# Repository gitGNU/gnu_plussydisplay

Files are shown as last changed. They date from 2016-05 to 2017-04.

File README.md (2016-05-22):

# Plussy Display Introduction

This repository contains free software and hardware design components for a small LED matrix resembling FSFE's plussy mascot. It is intended to be used, e.g., as an eyecatcher for fellowship events.

## License Information

All files in this project (except some configuration files where stated in their header) are licensed under the GPLv3 license as stated in the next section (GPLv3 License Statement).

## GPLv3 License Statement

Plussy Display
Copyright (C) 2015  Christian Carlowitz <chca@cmesh.de>

This program is free software: you can redistribute it and/or modify
it under the terms of the GNU General Public License as published by
the Free Software Foundation, either version 3 of the License, or
(at your option) any later version.

This program is distributed in the hope that it will be useful,
but WITHOUT ANY WARRANTY; without even the implied warranty of
MERCHANTABILITY or FITNESS FOR A PARTICULAR PURPOSE.  See the
GNU General Public License for more details.

You should have received a copy of the GNU General Public License
along with this program.  If not, see <http://www.gnu.org/licenses/>.

# Usage
## Adding new animations

* install dependencies for simulator (gcc, make, python2.7 including development headers, python-pygame)
* add new animation file in _uc/src/animations_, e.g., by copying an existing file
* rename animation function to match file name
* register animation function in _common.h_ for microcontroller (add declaration and _animTable_ entry)
* run `make ANIM=anim_funcname` in folder _sim_ to test

## Compiling microcontroller code

* install dependencies (gcc-arm-embedded from https://launchpad.net/gcc-arm-embedded, openocd, make)
* get libopencm3 (run `git submodule init`, enter _uc/libopencm3_, run `make`)
* run `make` or `make V=1` (verbose) in folder _uc_

## Flashing microcontroller

* find out openocd name for your JTAG adapter
* change parameter _OOCD_INTERFACE_ in file _uc/libopencm3.target.mk_ accordingly
* run `make flash` or `make flash V=1` (verbose) in folder _uc_

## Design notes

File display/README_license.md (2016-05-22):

# License Information

This directory contains laser cutter templates as `*.svg` files as well as PCB schematics, libraries and layouts created with KiCAD. All of these files, which partly do not support incorporating license information, are license under the GPLv3 license as stated in the following section.

## GPLv3 License Statement

Plussy Display
Copyright (C) 2015  Christian Carlowitz <chca@cmesh.de>

This program is free software: you can redistribute it and/or modify
it under the terms of the GNU General Public License as published by
the Free Software Foundation, either version 3 of the License, or
(at your option) any later version.

This program is distributed in the hope that it will be useful,
but WITHOUT ANY WARRANTY; without even the implied warranty of
MERCHANTABILITY or FITNESS FOR A PARTICULAR PURPOSE.  See the
GNU General Public License for more details.

You should have received a copy of the GNU General Public License
along with this program.  If not, see <http://www.gnu.org/licenses/>.

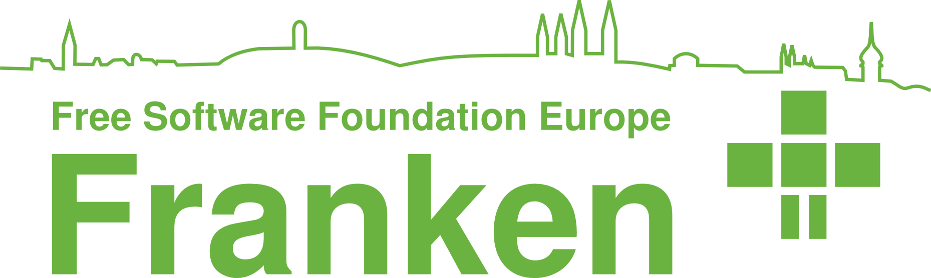
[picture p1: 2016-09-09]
server/fellowship_franken.png

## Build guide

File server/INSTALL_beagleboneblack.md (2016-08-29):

# License

Copying and distribution of this file, with or without modification,
are permitted in any medium without royalty provided the copyright
notice and this notice are preserved.  This file is offered as-is,
without any warranty.

# Installation on BeagleBoneBlack

Note: This script has been updated for Debian jessie based images; particularly these: http://elinux.org/Beagleboard:BeagleBoneBlack_Debian#Debian_Image_Testing_Snapshots

Log of all steps performed:
* remove `contrib` and `non-free` flags in `/etc/apt/sources.list` (use free software only)
* `apt-get update` and `apt-get upgrade`
* disable graphical interface: `update-rc.d -f lightdm remove`
* disable network service: `update-rc.d -f wicd remove`
* disable xrdp service: `update-rc.d -f xrdp remove`
* disable avahi: `update-rc.d -f avahi-daemon remove`
* `apt-get purge avahi-daemon`
* some error with led_aging startup script, added missing LSB info
* install `lsof`
* disable beagle bone services (occupying, e.g., port 80):
	* `systemctl disable bonescript.service`
	* `systemctl disable bonescript.socket`
	* `systemctl disable bonescript-autorun.service`
	* `systemctl disable cloud9.service`
	* `systemctl disable cloud9.socket`
* since some services are somehow enabled again by systemd:
	* `cd /lib/systemd/system`
	* `mv cloud9.service cloud9.service.disabled`
	* `mv cloud9.socket cloud9.socket.disabled`
* fimware for WLAN
	* recommended stick "TL-WN722N" (Atheros AR9271) requires firmware
	* free firmware not available in debian main
	* e.g., extract from Trisquel package "open-atk9k-htc-firmware": `/lib/firmware/htc_9271.fw`
* hostapd
	* install: `apt-get install hostapd  iw iwconfig wpa-supplicant`
	* add config `/etc/hostapd/hostapd.conf`
	* register config in `/etc/default/hostapd`
	* setup wlan0 in `/etc/network/interfaces`
* udhcpd
	* add config `/etc/udhcpd.conf.wlan0`
	* add post-up call to udhcpd
* set root password, set debian user password
* install python3: `apt-get install python3 python3-serial`
* install plussy server script:
	* copy to /usr/local/sbin
	* create user: `adduser --system --home /tmp --shell /bin/bash --no-create-home --disabled-login --ingroup dialout plussy`
	* register with systemd (copy script to `/etc/systemd/system/`)
* read-only rootfs:
	* add "ro" to to /boot/uboot/uEnv.txt (mmcargs)
	* add "ro" to "/" and "/boot/uboot" in /etc/fstab
	* add some temp filesystems (see fstab)
	* enhance bashrc (see bash.bashrc)
* apache
	* /etc/apache2/envvars: move log dir to /var/log (no subdir)
	* mv default site on 8080 to available (which disables it)
	* add new default site ("default" file, see below)
	* enable new default site with symlink
	* enable cgi with `a2enmod cgi`
* bind
	* `apt-get install bind9`
	* copy zone files, register fsfe zone (see files below)
* using UART different than UART1
	* install capemgr stuff according to `https://github.com/beagleboard/bb.org-overlays`
	* disable HDMI in /boot/uEnv.txt (uncomment `dtb=am335x-boneblack-emmc-overlay.dtb`)
	* enable UART5 with `cape_enable=bone_capemgr.enable_partno=BB-UART5`
	* change port to ttyO5 in `/etc/systemd/system/plussy-server.service`

Files:
* `/etc/hostapd/hostapd.conf`
* `/etc/udhcpd.conf.wlan0`
* `/etc/network/interfaces`
* `/etc/bash.bashrc`
* `/etc/fstab`
* `/etc/apache2/sites-available/default`
* `/etc/bind/{db.4.168.192,db.fsfe,named.conf.local}`
* `/etc/systemd/system/plussy-server.service`
* `/usr/local/sbin/server.py`
* `/var/www/server_web.py`

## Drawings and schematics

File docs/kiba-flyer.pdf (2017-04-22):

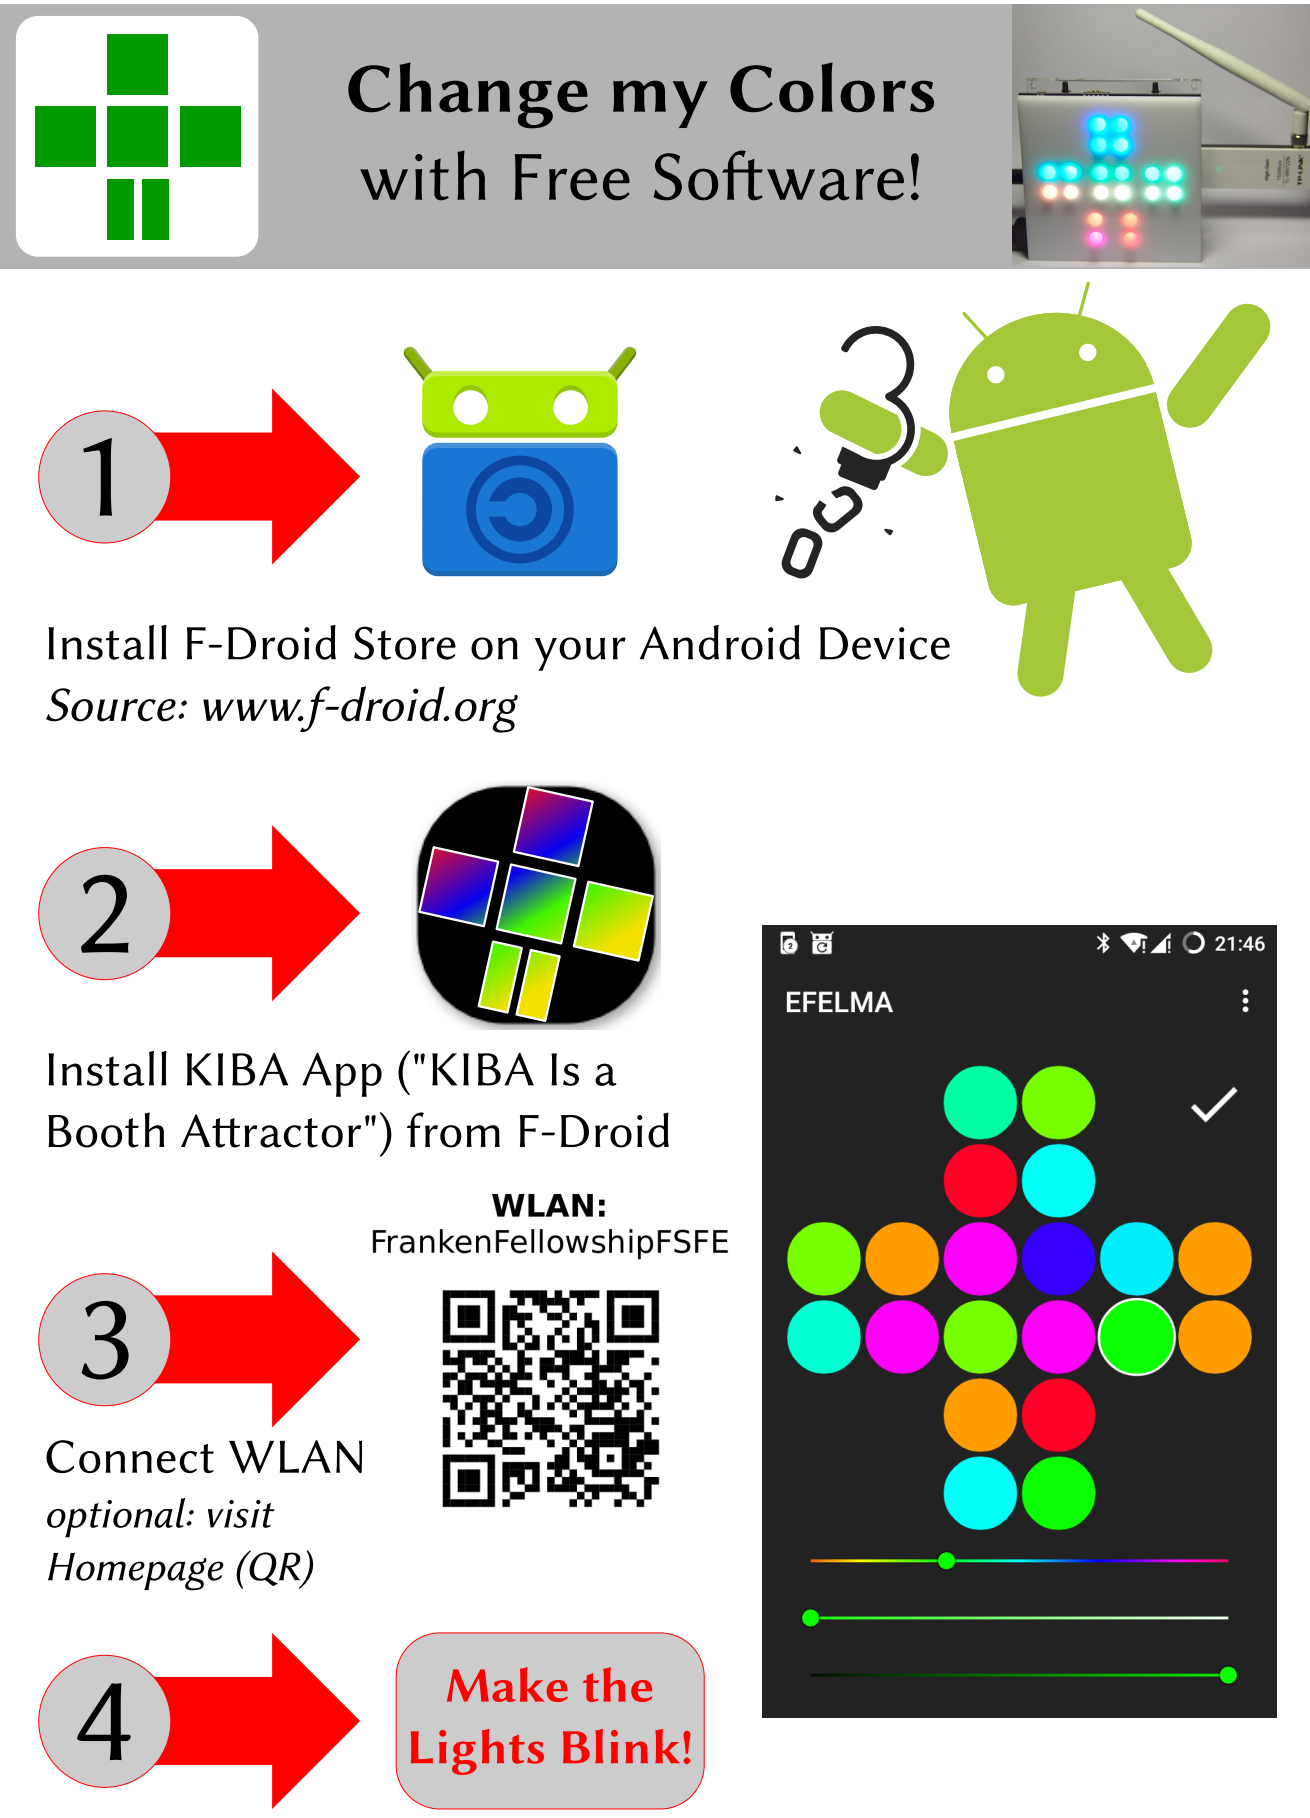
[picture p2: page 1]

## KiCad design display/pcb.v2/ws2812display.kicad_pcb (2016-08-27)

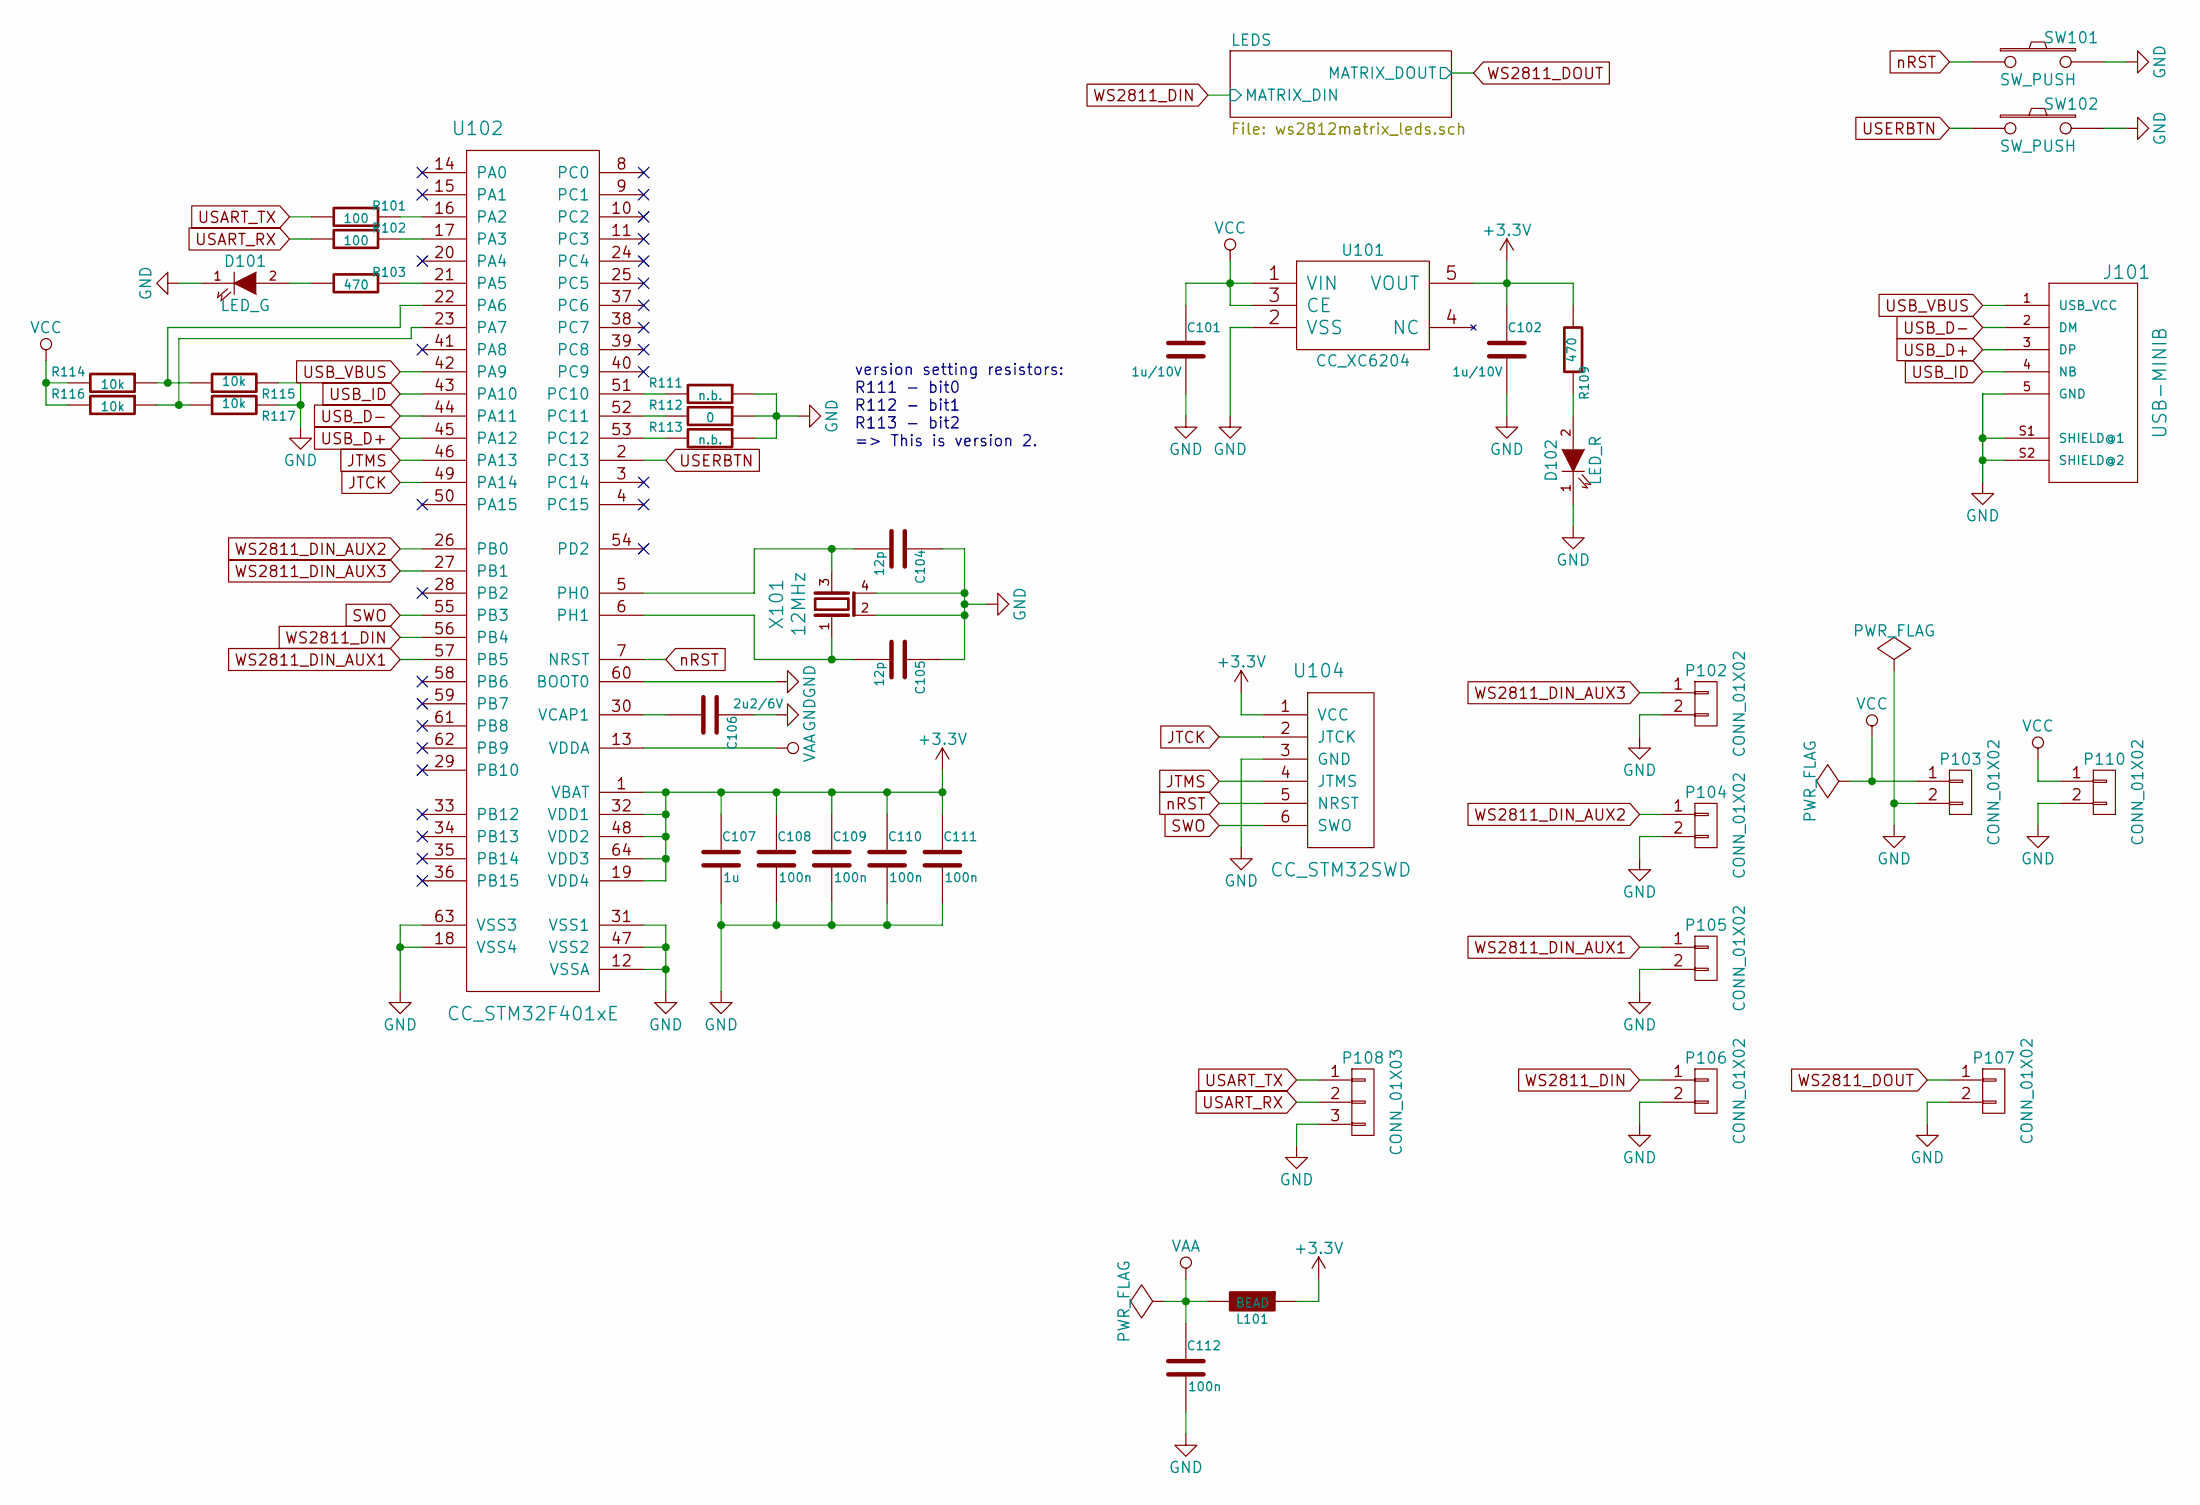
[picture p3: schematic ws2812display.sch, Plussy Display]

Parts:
C101, C102: 1u/10V; rcl-cc-0603
C104, C105: 12p; rcl-cc-0603
C106: 2u2/6V; rcl-cc-0603
C107: 1u; rcl-cc-0603
C108, C109, C110, C111, C112: 100n; rcl-cc-0603
D101: LED_G; LED-0603
D102: LED_R; LED-0603
J101: USB-MINIB; con-usb-USB-B-MINI-THD
L101: BEAD; rcl-cc-0603
P102, P104, P105, P106, P107: CONN_01X02; Pin_Header_Straight_1x02
P103, P110: CONN_01X02; con-ria-TYPE_230_249_2PIN
P108: CONN_01X03; Pin_Header_Straight_1x03
R101, R102: 100; rcl-cc-0603
R103, R109: 470; rcl-cc-0603
R111, R113: n.b.; rcl-cc-0603
R112: 0; rcl-cc-0603
R114, R115, R116, R117: 10k; rcl-cc-0603
SW101, SW102: SW_PUSH; TASTER_3305B
U101: CC_XC6204; SOT23-5
U102: CC_STM32F401xE; lqfp64
U104: CC_STM32SWD; Pin_Header_Straight_1x06
X101: 12MHz; Q_EUROQUARTZ_MJ_3x5x1

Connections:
+3V3: C102.1, C107.1, C108.1, C109.1, C110.1, C111.1, L101.1, R109.2, U101.5 (VOUT), U102.1 (VBAT), U102.19 (VDD4), U102.32 (VDD1), U102.48 (VDD2), U102.64 (VDD3), U104.1 (VCC)
GND: C101.2, C102.2, C104.1, C105.1, C106.1, C107.2, C108.2, C109.2, C110.2, C111.2, C112.2, D101.1 (K), D102.1 (K), J101.5 (GND), J101.S1 (SHIELD@1), J101.S2 (SHIELD@2), P102.2, P103.2, P104.2, P105.2, P106.2, P107.2, P108.3, P110.2, R111.1, R112.1, R113.1, R115.2, R117.2, SW101.2, SW102.2, U101.2 (VSS), U102.12 (VSSA), U102.18 (VSS4), U102.31 (VSS1), U102.47 (VSS2), U102.60 (BOOT0), U102.63 (VSS3), U104.3 (GND), X101.2 (GND), X101.4 (GND); also elsewhere on the board
JTCK: U102.49 (PA14), U104.2 (JTCK)
JTMS: U102.46 (PA13), U104.4 (JTMS)
unnamed: C104.2, U102.5 (PH0), X101.3
unnamed: C105.2, U102.6 (PH1), X101.1
unnamed: C106.2, U102.30 (VCAP1)
unnamed: D101.2 (A), R103.2
unnamed: D102.2 (A), R109.1
unnamed: R101.1, U102.16 (PA2)
unnamed: R102.1, U102.17 (PA3)
unnamed: R103.1, U102.21 (PA5)
unnamed: R111.2, U102.51 (PC10)
unnamed: R112.2, U102.52 (PC11)
unnamed: R113.2, U102.53 (PC12)
unnamed: R114.1, R115.1, U102.22 (PA6)
unnamed: R116.1, R117.1, U102.23 (PA7)
SWO: U102.55 (PB3), U104.6 (SWO)
USART_RX: P108.2, R102.2
USART_TX: P108.1, R101.2
USB_D+: J101.3 (DP), U102.45 (PA12)
USB_D-: J101.2 (DM), U102.44 (PA11)
USB_ID: J101.4 (NB), U102.43 (PA10)
USB_VBUS: J101.1 (USB_VCC), U102.42 (PA9)
USERBTN: SW102.1, U102.2 (PC13)
VAA: C112.1, L101.2, U102.13 (VDDA)
VCC: C101.1, P103.1, P110.1, R114.2, R116.2, U101.1 (VIN), U101.3 (CE); also elsewhere on the board
WS2811_DIN: P106.1, U102.56 (PB4); also elsewhere on the board
WS2811_DIN_AUX1: P105.1, U102.57 (PB5)
WS2811_DIN_AUX2: P104.1, U102.26 (PB0)
WS2811_DIN_AUX3: P102.1, U102.27 (PB1)
WS2811_DOUT: P107.1; also elsewhere on the board
nRST: SW101.1, U102.7 (NRST), U104.5 (NRST)

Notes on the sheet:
version setting resistors: R111 - bit0 R112 - bit1 R113 - bit2 => This is version 2.

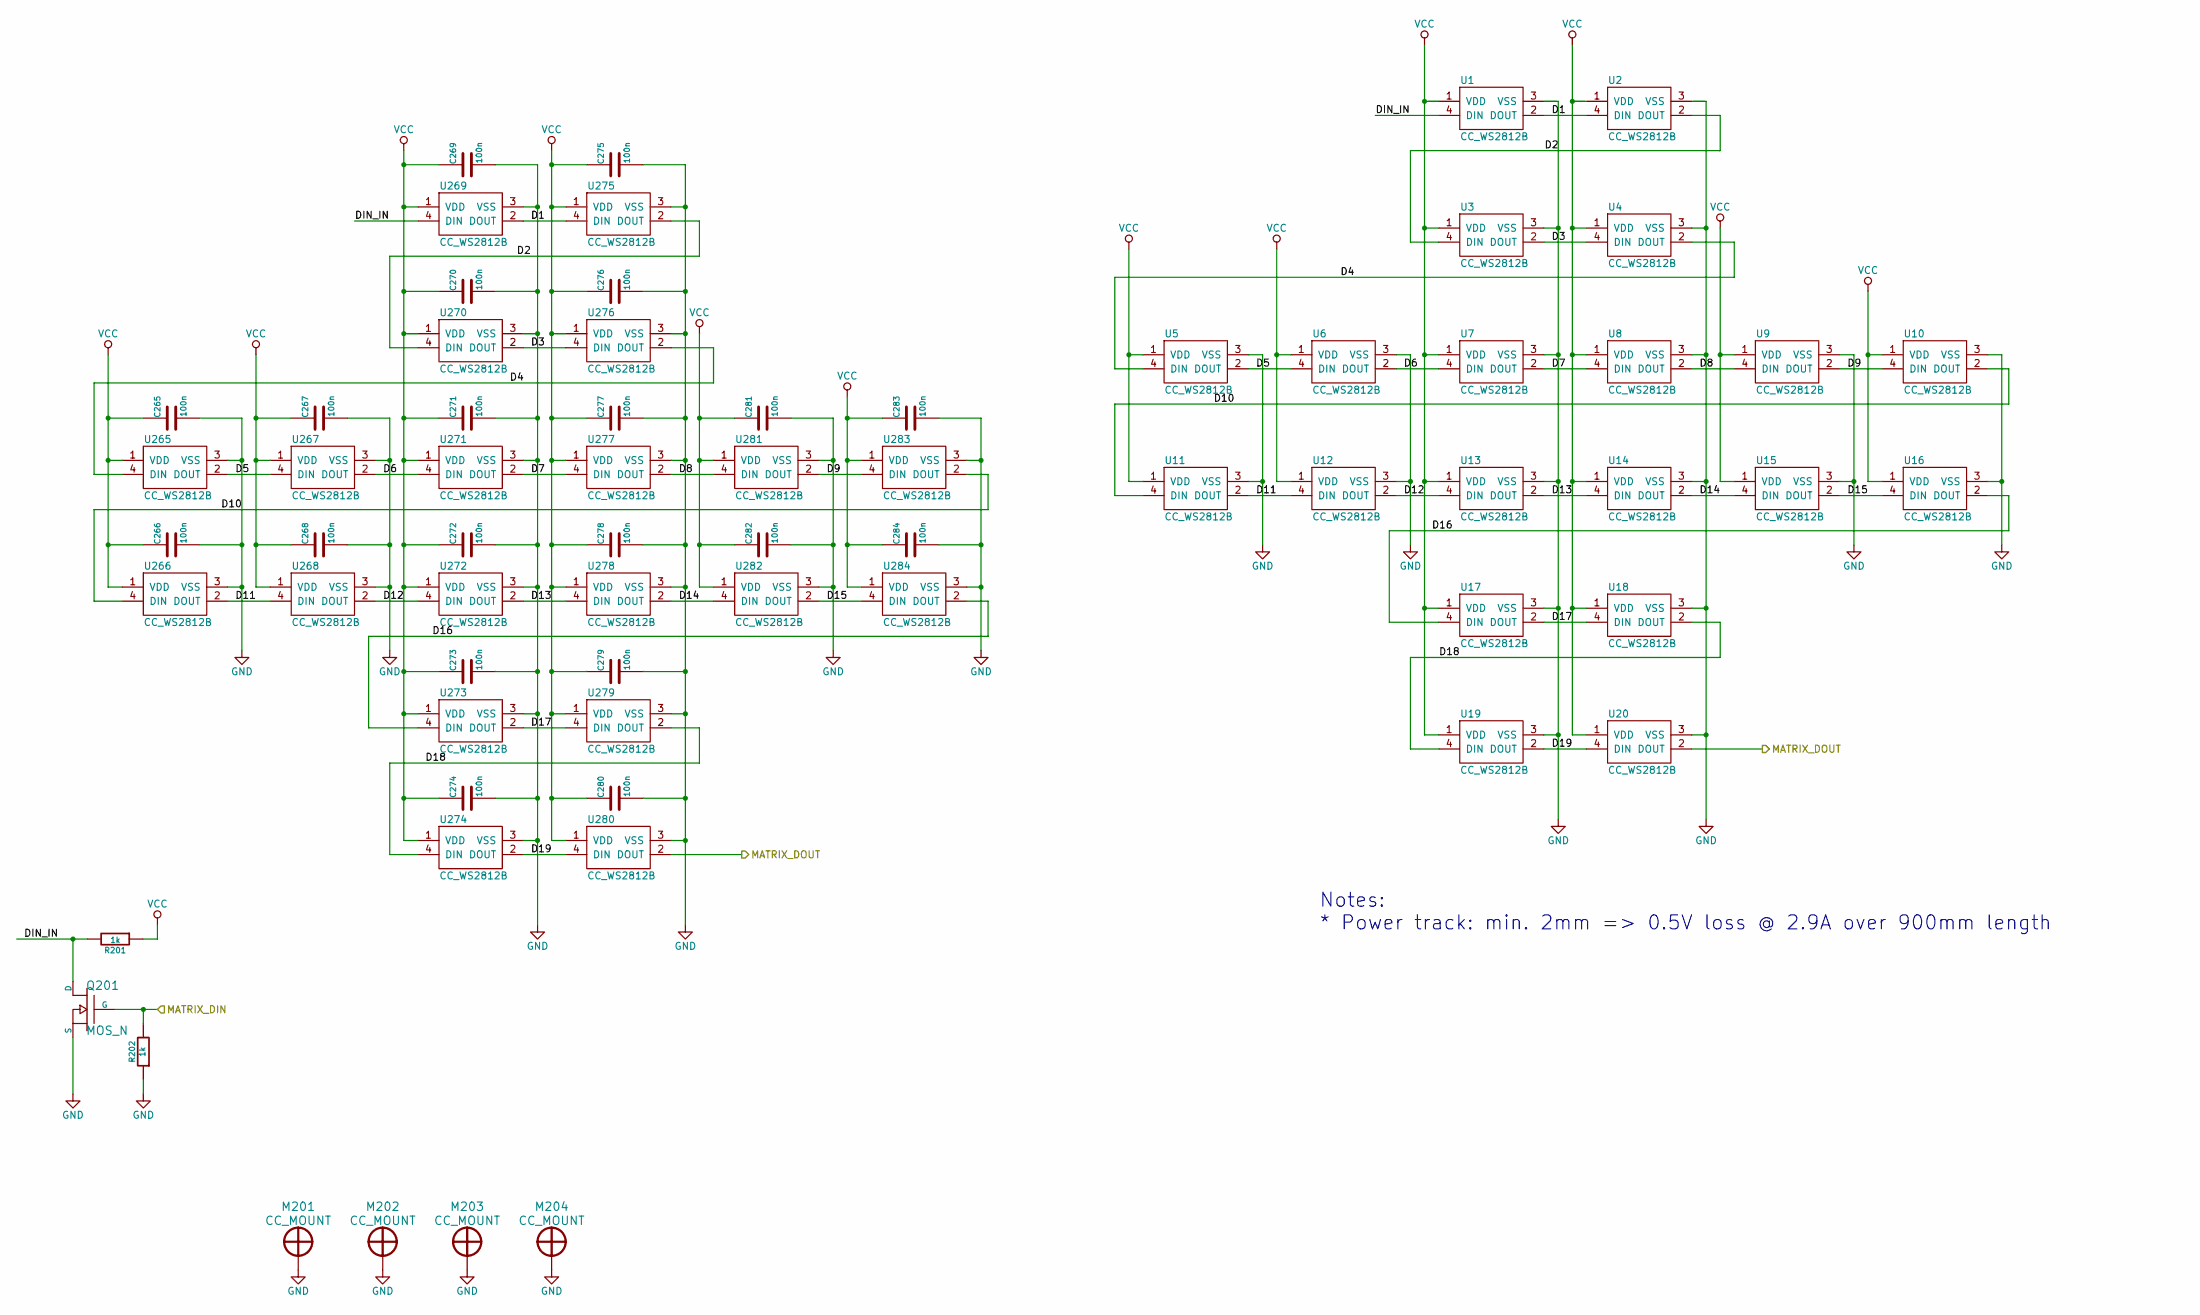
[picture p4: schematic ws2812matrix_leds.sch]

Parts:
C265, C266, C267, C268, C269, C270, C271, C272, C273, C274, C275, C276, C277, C278, C279, C280, C281, C282, C283, C284: 100n; rcl-cc-0603
M201, M202, M203, M204: CC_MOUNT; CC_MOUNT_PLATED_M3
Q201: MOS_N; CC_SOT23_MOS1
R201, R202: 1k; rcl-cc-0603
U1, U2, U3, U4, U5, U6, U7, U8, U9, U10, U11, U12, U13, U14, U15, U16, U17, U18, U19, U20: CC_WS2812B; WS2812B
U265, U266, U267, U268, U269, U270, U271, U272, U273, U274, U275, U276, U277, U278, U279, U280, U281, U282, U283, U284: CC_WS2812B; WS2812B_DUAL

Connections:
/LEDS/D1: U1.2 (DOUT), U2.4 (DIN), U269.2 (DOUT), U275.4 (DIN)
/LEDS/D2: U2.2 (DOUT), U3.4 (DIN), U270.4 (DIN), U275.2 (DOUT)
/LEDS/D3: U3.2 (DOUT), U4.4 (DIN), U270.2 (DOUT), U276.4 (DIN)
/LEDS/D4: U4.2 (DOUT), U5.4 (DIN), U265.4 (DIN), U276.2 (DOUT)
/LEDS/D5: U5.2 (DOUT), U6.4 (DIN), U265.2 (DOUT), U267.4 (DIN)
/LEDS/D6: U6.2 (DOUT), U7.4 (DIN), U267.2 (DOUT), U271.4 (DIN)
/LEDS/D7: U7.2 (DOUT), U8.4 (DIN), U271.2 (DOUT), U277.4 (DIN)
/LEDS/D8: U8.2 (DOUT), U9.4 (DIN), U277.2 (DOUT), U281.4 (DIN)
/LEDS/D9: U9.2 (DOUT), U10.4 (DIN), U281.2 (DOUT), U283.4 (DIN)
/LEDS/D10: U10.2 (DOUT), U11.4 (DIN), U266.4 (DIN), U283.2 (DOUT)
/LEDS/D11: U11.2 (DOUT), U12.4 (DIN), U266.2 (DOUT), U268.4 (DIN)
/LEDS/D12: U12.2 (DOUT), U13.4 (DIN), U268.2 (DOUT), U272.4 (DIN)
/LEDS/D13: U13.2 (DOUT), U14.4 (DIN), U272.2 (DOUT), U278.4 (DIN)
/LEDS/D14: U14.2 (DOUT), U15.4 (DIN), U278.2 (DOUT), U282.4 (DIN)
/LEDS/D15: U15.2 (DOUT), U16.4 (DIN), U282.2 (DOUT), U284.4 (DIN)
/LEDS/D16: U16.2 (DOUT), U17.4 (DIN), U273.4 (DIN), U284.2 (DOUT)
/LEDS/D17: U17.2 (DOUT), U18.4 (DIN), U273.2 (DOUT), U279.4 (DIN)
/LEDS/D18: U18.2 (DOUT), U19.4 (DIN), U274.4 (DIN), U279.2 (DOUT)
/LEDS/D19: U19.2 (DOUT), U20.4 (DIN), U274.2 (DOUT), U280.4 (DIN)
/LEDS/DIN_IN: Q201.D, R201.2, U1.4 (DIN), U269.4 (DIN)
GND: C265.2, C266.2, C267.2, C268.2, C269.2, C270.2, C271.2, C272.2, C273.2, C274.2, C275.2, C276.2, C277.2, C278.2, C279.2, C280.2, C281.2, C282.2, C283.2, C284.2, M201.1, M202.1, M203.1, M204.1, Q201.S, R202.1, U1.3 (VSS), U2.3 (VSS), U3.3 (VSS), U4.3 (VSS), U5.3 (VSS), U6.3 (VSS), U7.3 (VSS), U8.3 (VSS), U9.3 (VSS), U10.3 (VSS), U11.3 (VSS), U12.3 (VSS), U13.3 (VSS), U14.3 (VSS), U15.3 (VSS), U16.3 (VSS), U17.3 (VSS), U18.3 (VSS), U19.3 (VSS), U20.3 (VSS), U265.3 (VSS), U266.3 (VSS), U267.3 (VSS), U268.3 (VSS), U269.3 (VSS), U270.3 (VSS), U271.3 (VSS), U272.3 (VSS), U273.3 (VSS), U274.3 (VSS), U275.3 (VSS), U276.3 (VSS), U277.3 (VSS), U278.3 (VSS), U279.3 (VSS), U280.3 (VSS), U281.3 (VSS), U282.3 (VSS), U283.3 (VSS), U284.3 (VSS); also elsewhere on the board
VCC: C265.1, C266.1, C267.1, C268.1, C269.1, C270.1, C271.1, C272.1, C273.1, C274.1, C275.1, C276.1, C277.1, C278.1, C279.1, C280.1, C281.1, C282.1, C283.1, C284.1, R201.1, U1.1 (VDD), U2.1 (VDD), U3.1 (VDD), U4.1 (VDD), U5.1 (VDD), U6.1 (VDD), U7.1 (VDD), U8.1 (VDD), U9.1 (VDD), U10.1 (VDD), U11.1 (VDD), U12.1 (VDD), U13.1 (VDD), U14.1 (VDD), U15.1 (VDD), U16.1 (VDD), U17.1 (VDD), U18.1 (VDD), U19.1 (VDD), U20.1 (VDD), U265.1 (VDD), U266.1 (VDD), U267.1 (VDD), U268.1 (VDD), U269.1 (VDD), U270.1 (VDD), U271.1 (VDD), U272.1 (VDD), U273.1 (VDD), U274.1 (VDD), U275.1 (VDD), U276.1 (VDD), U277.1 (VDD), U278.1 (VDD), U279.1 (VDD), U280.1 (VDD), U281.1 (VDD), U282.1 (VDD), U283.1 (VDD), U284.1 (VDD); also elsewhere on the board
WS2811_DIN: Q201.G, R202.2; also elsewhere on the board
WS2811_DOUT: U20.2 (DOUT), U280.2 (DOUT); also elsewhere on the board

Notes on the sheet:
Notes: * Power track: min. 2mm => 0.5V loss @ 2.9A over 900mm length

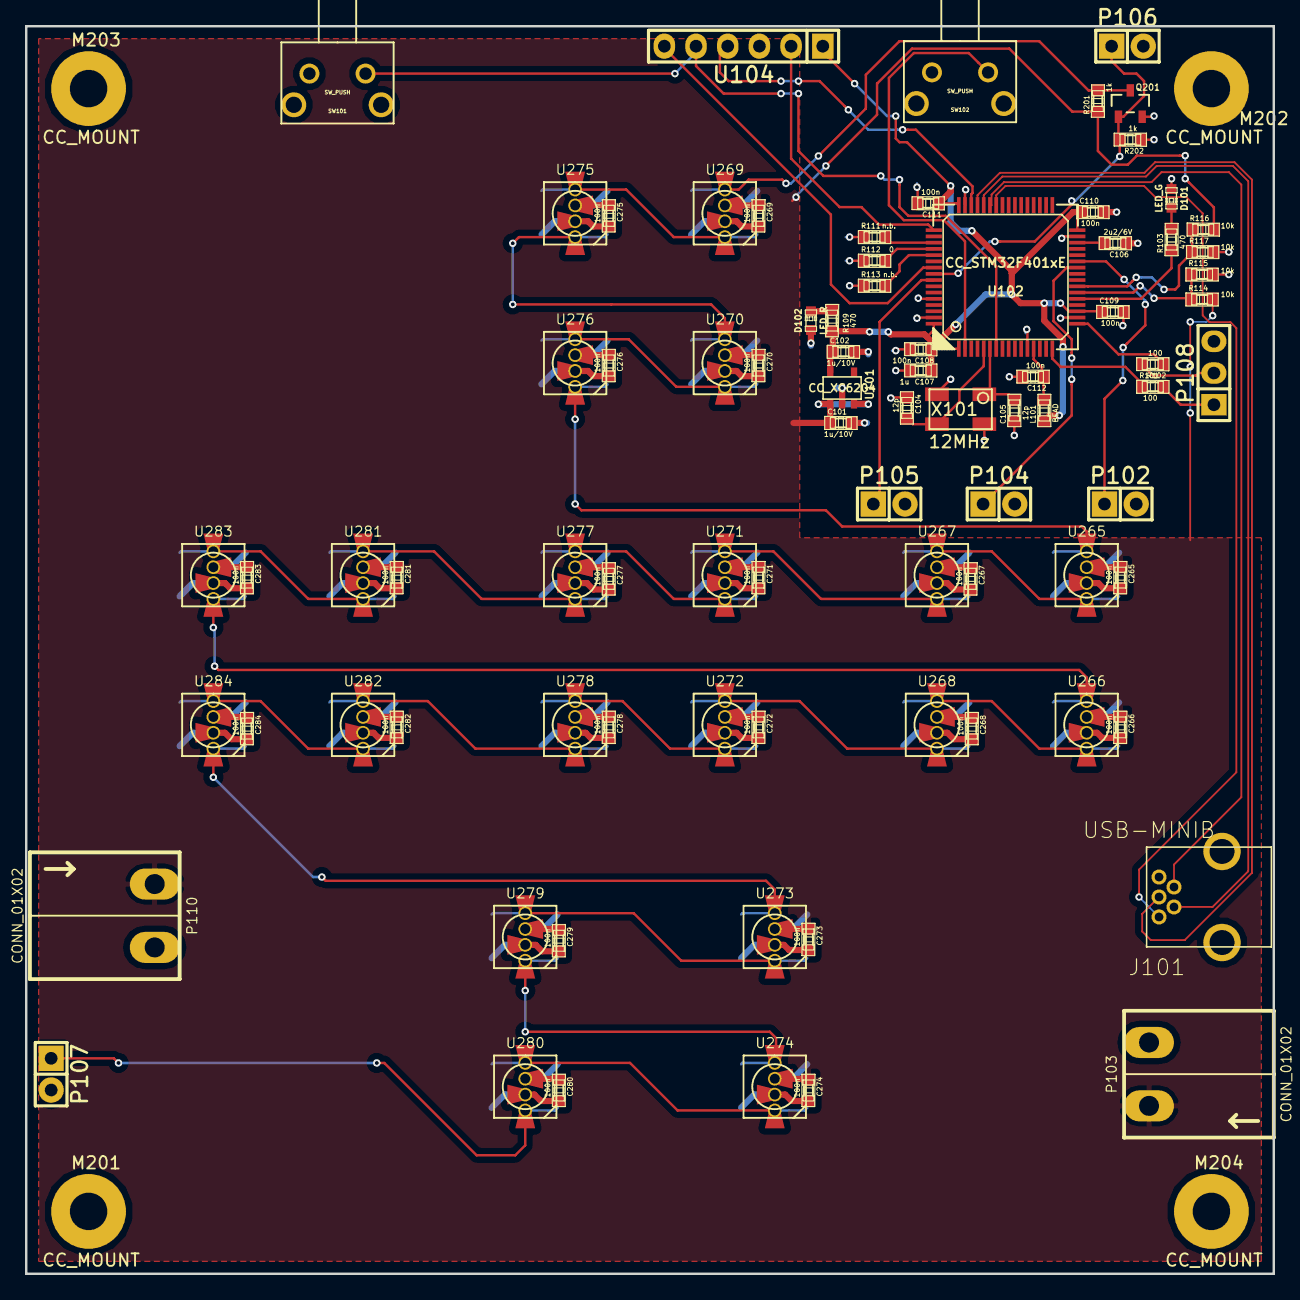
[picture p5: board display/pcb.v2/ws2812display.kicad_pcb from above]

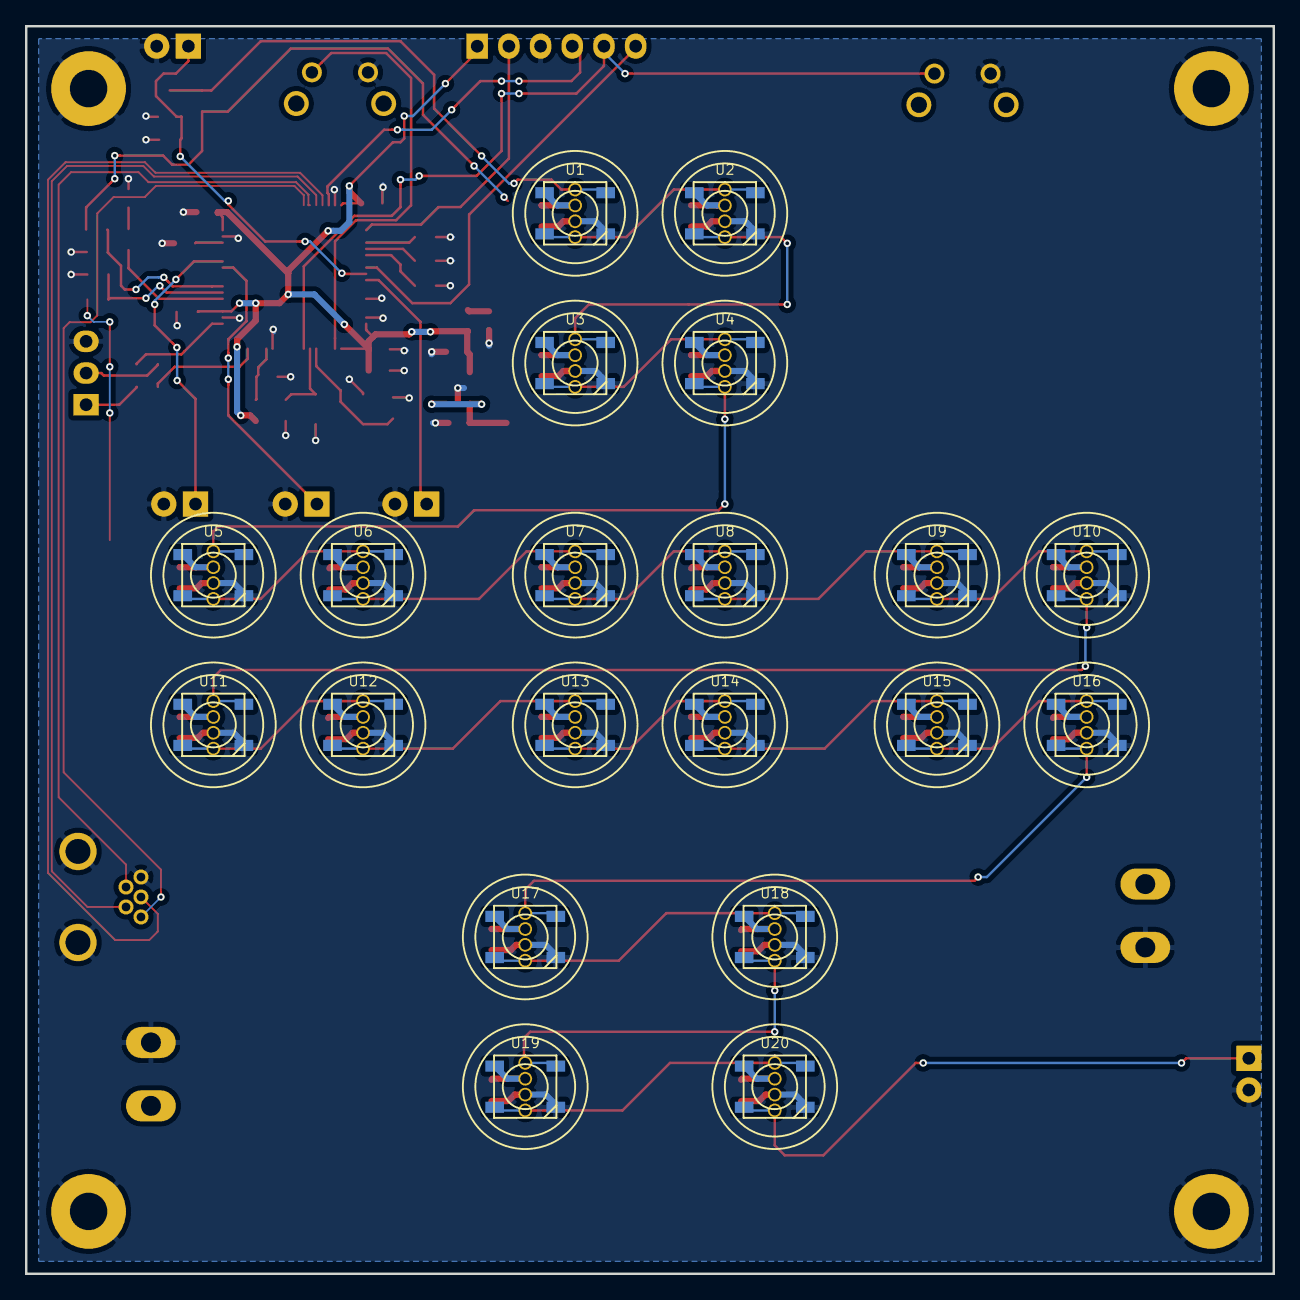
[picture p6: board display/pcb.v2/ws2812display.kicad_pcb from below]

Board: 2 copper layers, 100.0 x 100.0 mm, 107 parts (20 on the bottom side), 53 nets.

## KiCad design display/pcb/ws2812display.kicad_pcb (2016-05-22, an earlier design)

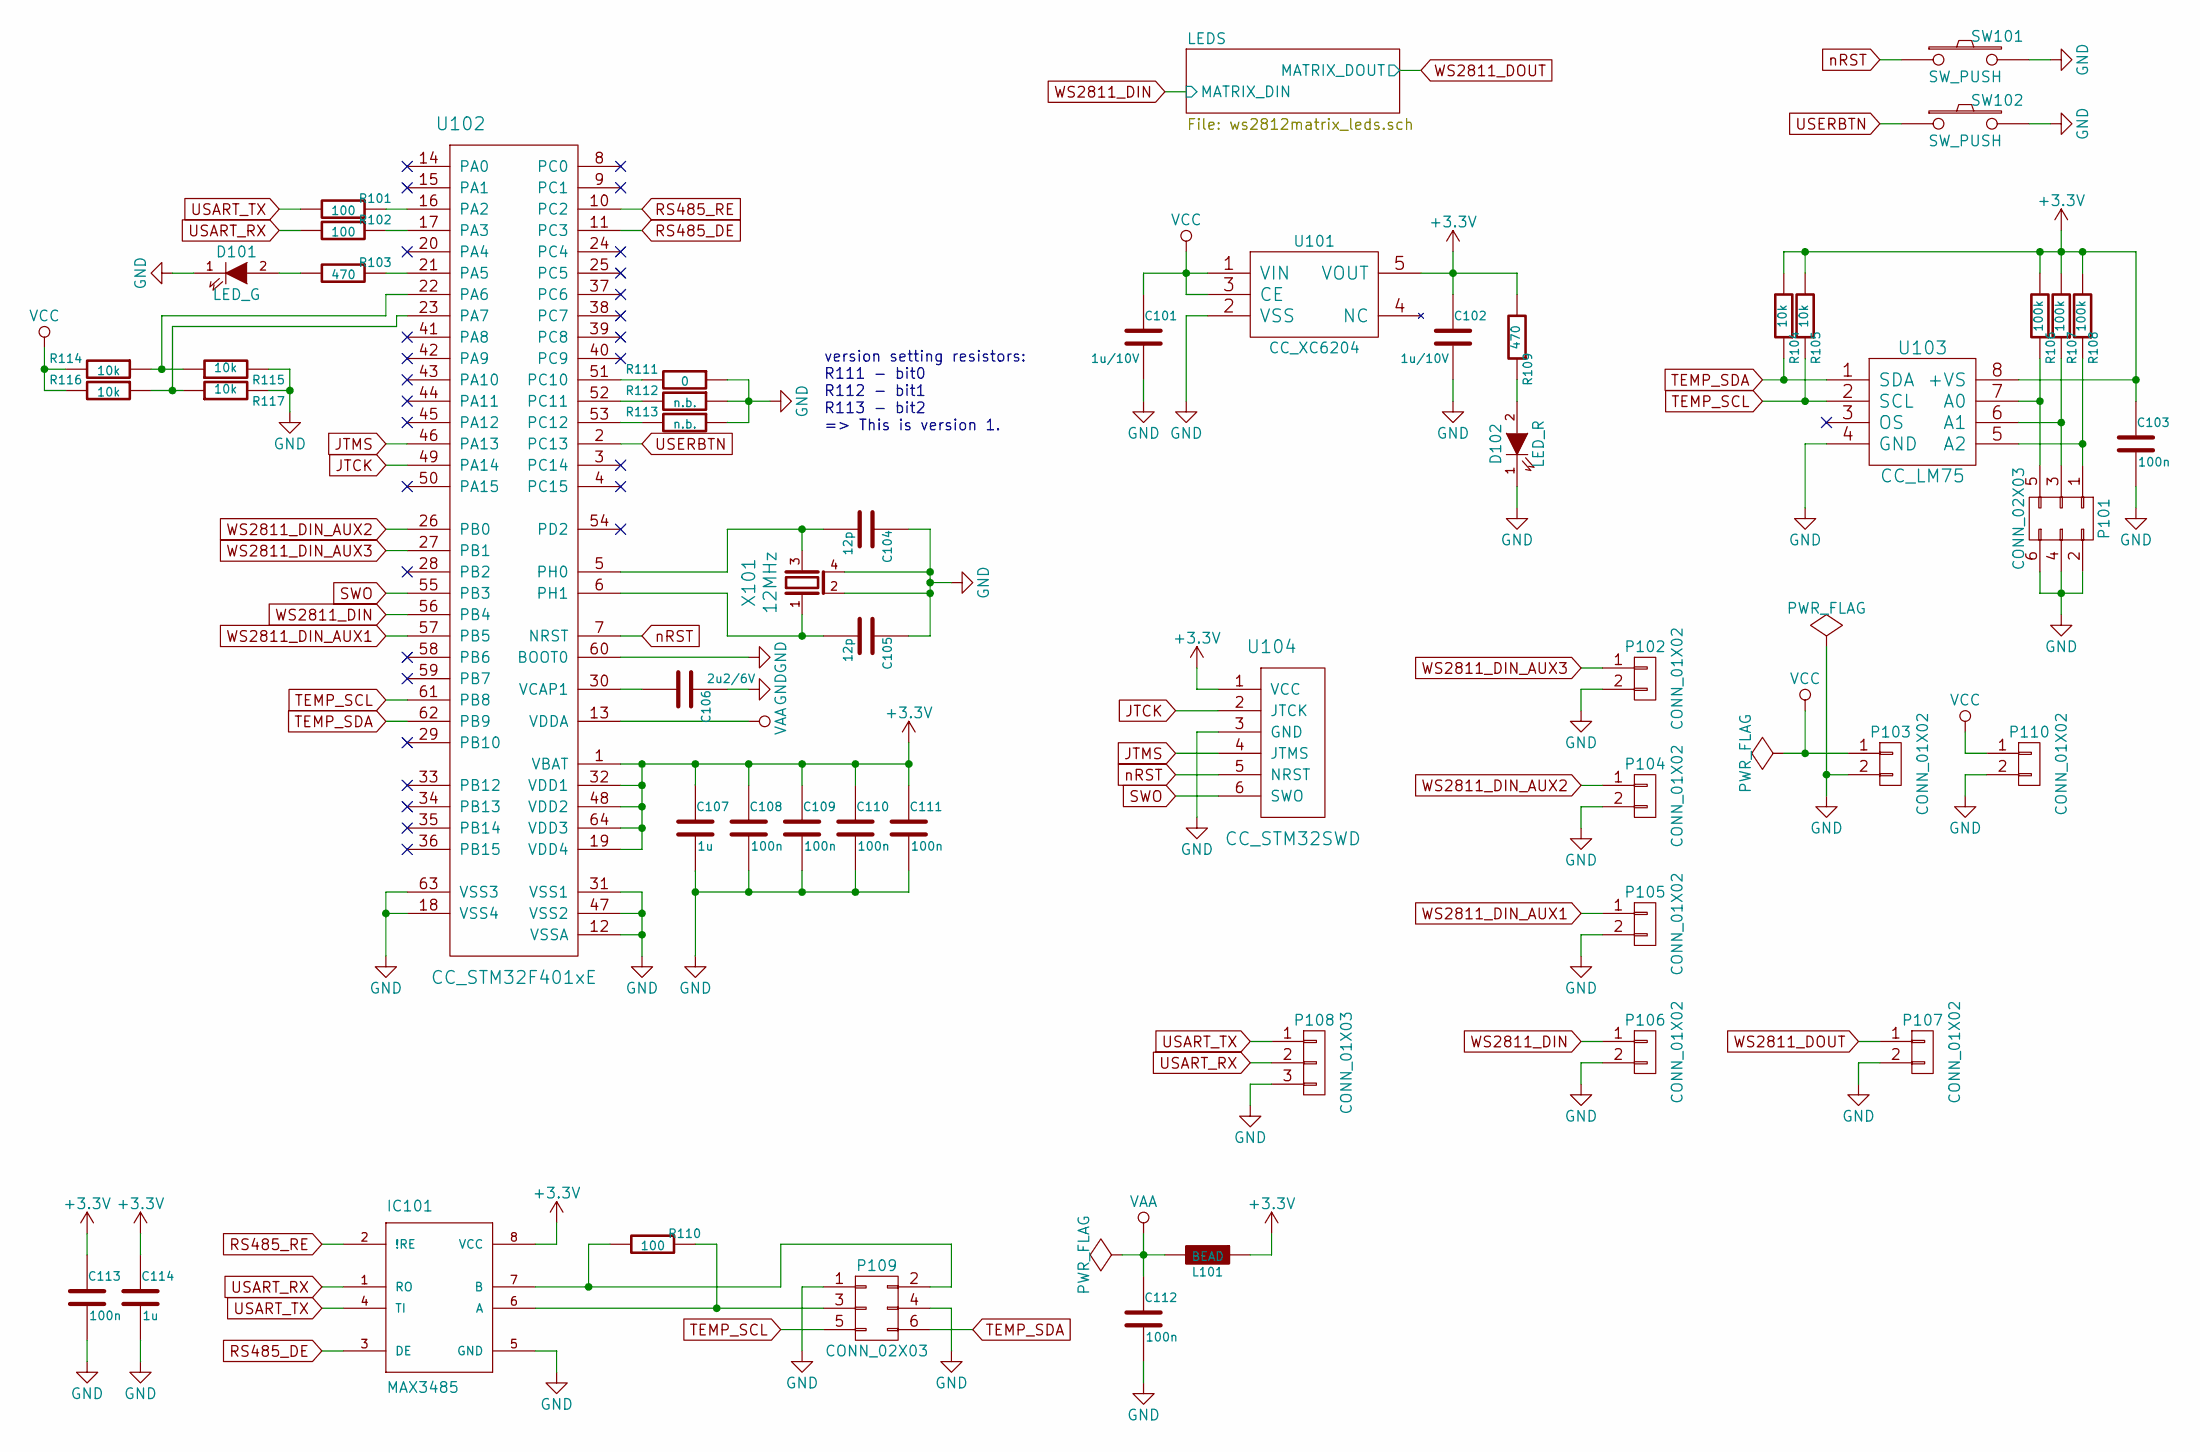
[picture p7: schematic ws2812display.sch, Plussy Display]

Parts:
C101, C102: 1u/10V; rcl-cc-0603
C103, C108, C109, C110, C111, C112, C113: 100n; rcl-cc-0603
C104, C105: 12p; rcl-cc-0603
C106: 2u2/6V; rcl-cc-0603
C107, C114: 1u; rcl-cc-0603
D101: LED_G; LED-0603
D102: LED_R; LED-0603
IC101: MAX3485; if-driver-SO08
L101: BEAD; rcl-cc-0603
P101: CONN_02X03; Pin_Header_Straight_2x03
P102, P104, P105, P106, P107: CONN_01X02; Pin_Header_Straight_1x02
P103, P110: CONN_01X02; con-ria-TYPE_230_249_2PIN
P108: CONN_01X03; Pin_Header_Straight_1x03
P109: CONN_02X03; con-harting-ml-ML6
R101, R102, R110: 100; rcl-cc-0603
R103, R109: 470; rcl-cc-0603
R104, R105, R114, R115, R116, R117: 10k; rcl-cc-0603
R106, R107, R108: 100k; rcl-cc-0603
R111: 0; rcl-cc-0603
R112, R113: n.b.; rcl-cc-0603
SW101, SW102: SW_PUSH; TASTER_3305B
U101: CC_XC6204; SOT23-5
U102: CC_STM32F401xE; lqfp64
U103: CC_LM75; SOIC-8_N
U104: CC_STM32SWD; Pin_Header_Straight_1x06
X101: 12MHz; Q_EUROQUARTZ_MJ_3x5x1

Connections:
+3V3: C102.1, C103.1, C107.1, C108.1, C109.1, C110.1, C111.1, C113.1, C114.1, IC101.8 (VCC), L101.1, R104.2, R105.2, R106.2, R107.2, R108.2, R109.2, U101.5 (VOUT), U102.1 (VBAT), U102.19 (VDD4), U102.32 (VDD1), U102.48 (VDD2), U102.64 (VDD3), U103.8 (+VS), U104.1 (VCC)
GND: C101.2, C102.2, C103.2, C104.1, C105.1, C106.1, C107.2, C108.2, C109.2, C110.2, C111.2, C112.2, C113.2, C114.2, D101.1 (K), D102.1 (K), IC101.5 (GND), P101.2, P101.4, P101.6, P102.2, P103.2, P104.2, P105.2, P106.2, P107.2, P108.3, P109.1, P109.4, P110.2, R111.1, R112.1, R113.1, R115.2, R117.2, SW101.2, SW102.2, U101.2 (VSS), U102.12 (VSSA), U102.18 (VSS4), U102.31 (VSS1), U102.47 (VSS2), U102.60 (BOOT0), U102.63 (VSS3), U103.4 (GND), U104.3 (GND), X101.2 (GND), X101.4 (GND); also elsewhere on the board
JTCK: U102.49 (PA14), U104.2 (JTCK)
JTMS: U102.46 (PA13), U104.4 (JTMS)
unnamed: C104.2, U102.5 (PH0), X101.3
unnamed: C105.2, U102.6 (PH1), X101.1
unnamed: C106.2, U102.30 (VCAP1)
unnamed: D101.2 (A), R103.2
unnamed: D102.2 (A), R109.1
unnamed: IC101.6 (A), P109.3, R110.1
unnamed: IC101.7 (B), P109.2, R110.2
unnamed: P101.1, R108.1, U103.5 (A2)
unnamed: P101.3, R107.1, U103.6 (A1)
unnamed: P101.5, R106.1, U103.7 (A0)
unnamed: R101.1, U102.16 (PA2)
unnamed: R102.1, U102.17 (PA3)
unnamed: R103.1, U102.21 (PA5)
unnamed: R111.2, U102.51 (PC10)
unnamed: R112.2, U102.52 (PC11)
unnamed: R113.2, U102.53 (PC12)
unnamed: R114.1, R115.1, U102.22 (PA6)
unnamed: R116.1, R117.1, U102.23 (PA7)
RS485_DE: IC101.3 (DE), U102.11 (PC3)
RS485_RE: IC101.2 (!RE), U102.10 (PC2)
SWO: U102.55 (PB3), U104.6 (SWO)
TEMP_SCL: P109.5, R105.1, U102.61 (PB8), U103.2 (SCL)
TEMP_SDA: P109.6, R104.1, U102.62 (PB9), U103.1 (SDA)
USART_RX: IC101.1 (RO), P108.2, R102.2
USART_TX: IC101.4 (TI), P108.1, R101.2
USERBTN: SW102.1, U102.2 (PC13)
VAA: C112.1, L101.2, U102.13 (VDDA)
VCC: C101.1, P103.1, P110.1, R114.2, R116.2, U101.1 (VIN), U101.3 (CE); also elsewhere on the board
WS2811_DIN: P106.1, U102.56 (PB4); also elsewhere on the board
WS2811_DIN_AUX1: P105.1, U102.57 (PB5)
WS2811_DIN_AUX2: P104.1, U102.26 (PB0)
WS2811_DIN_AUX3: P102.1, U102.27 (PB1)
WS2811_DOUT: P107.1; also elsewhere on the board
nRST: SW101.1, U102.7 (NRST), U104.5 (NRST)

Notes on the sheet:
version setting resistors: R111 - bit0 R112 - bit1 R113 - bit2 => This is version 1.

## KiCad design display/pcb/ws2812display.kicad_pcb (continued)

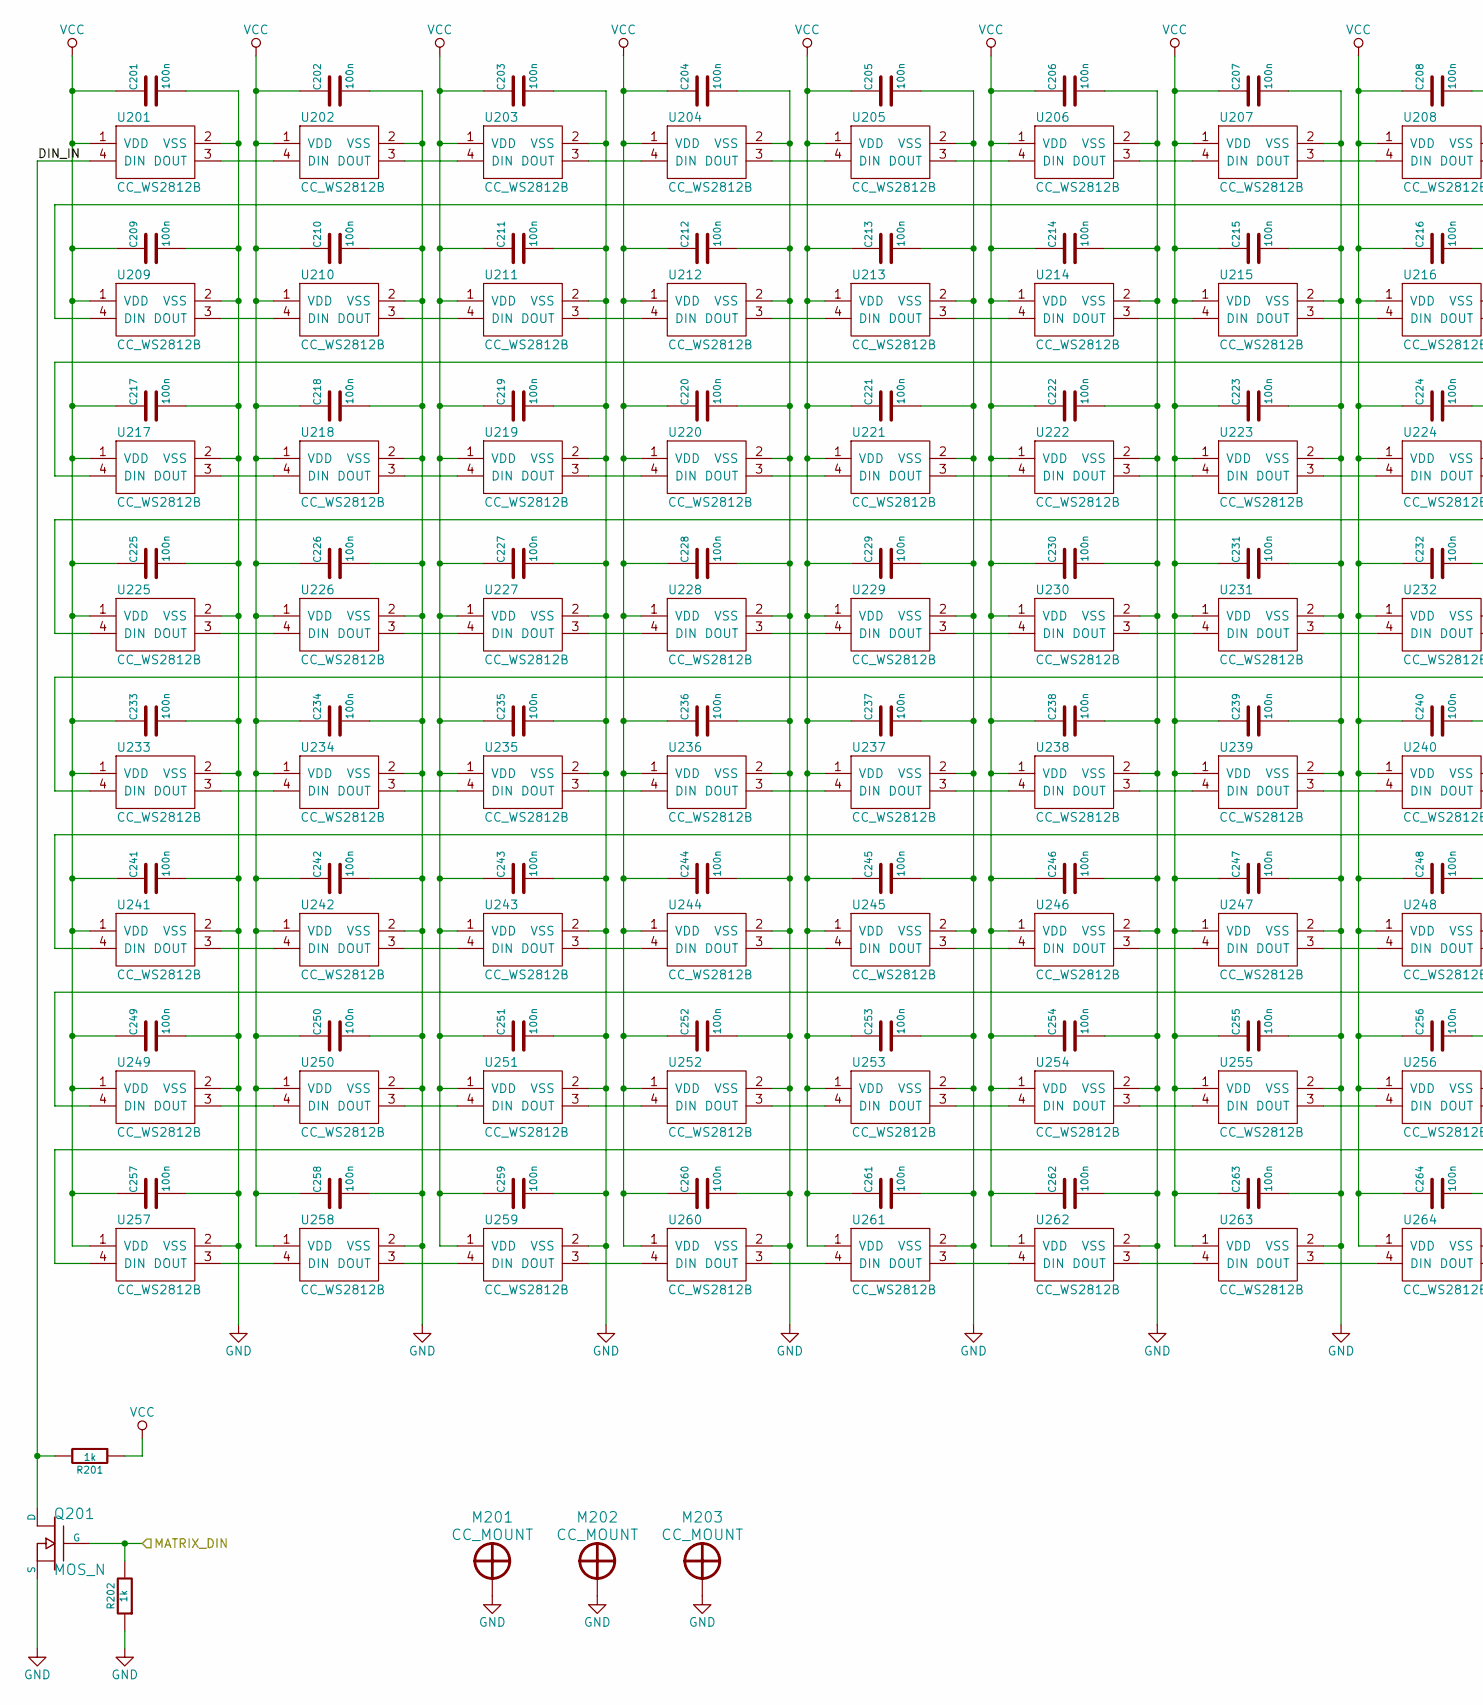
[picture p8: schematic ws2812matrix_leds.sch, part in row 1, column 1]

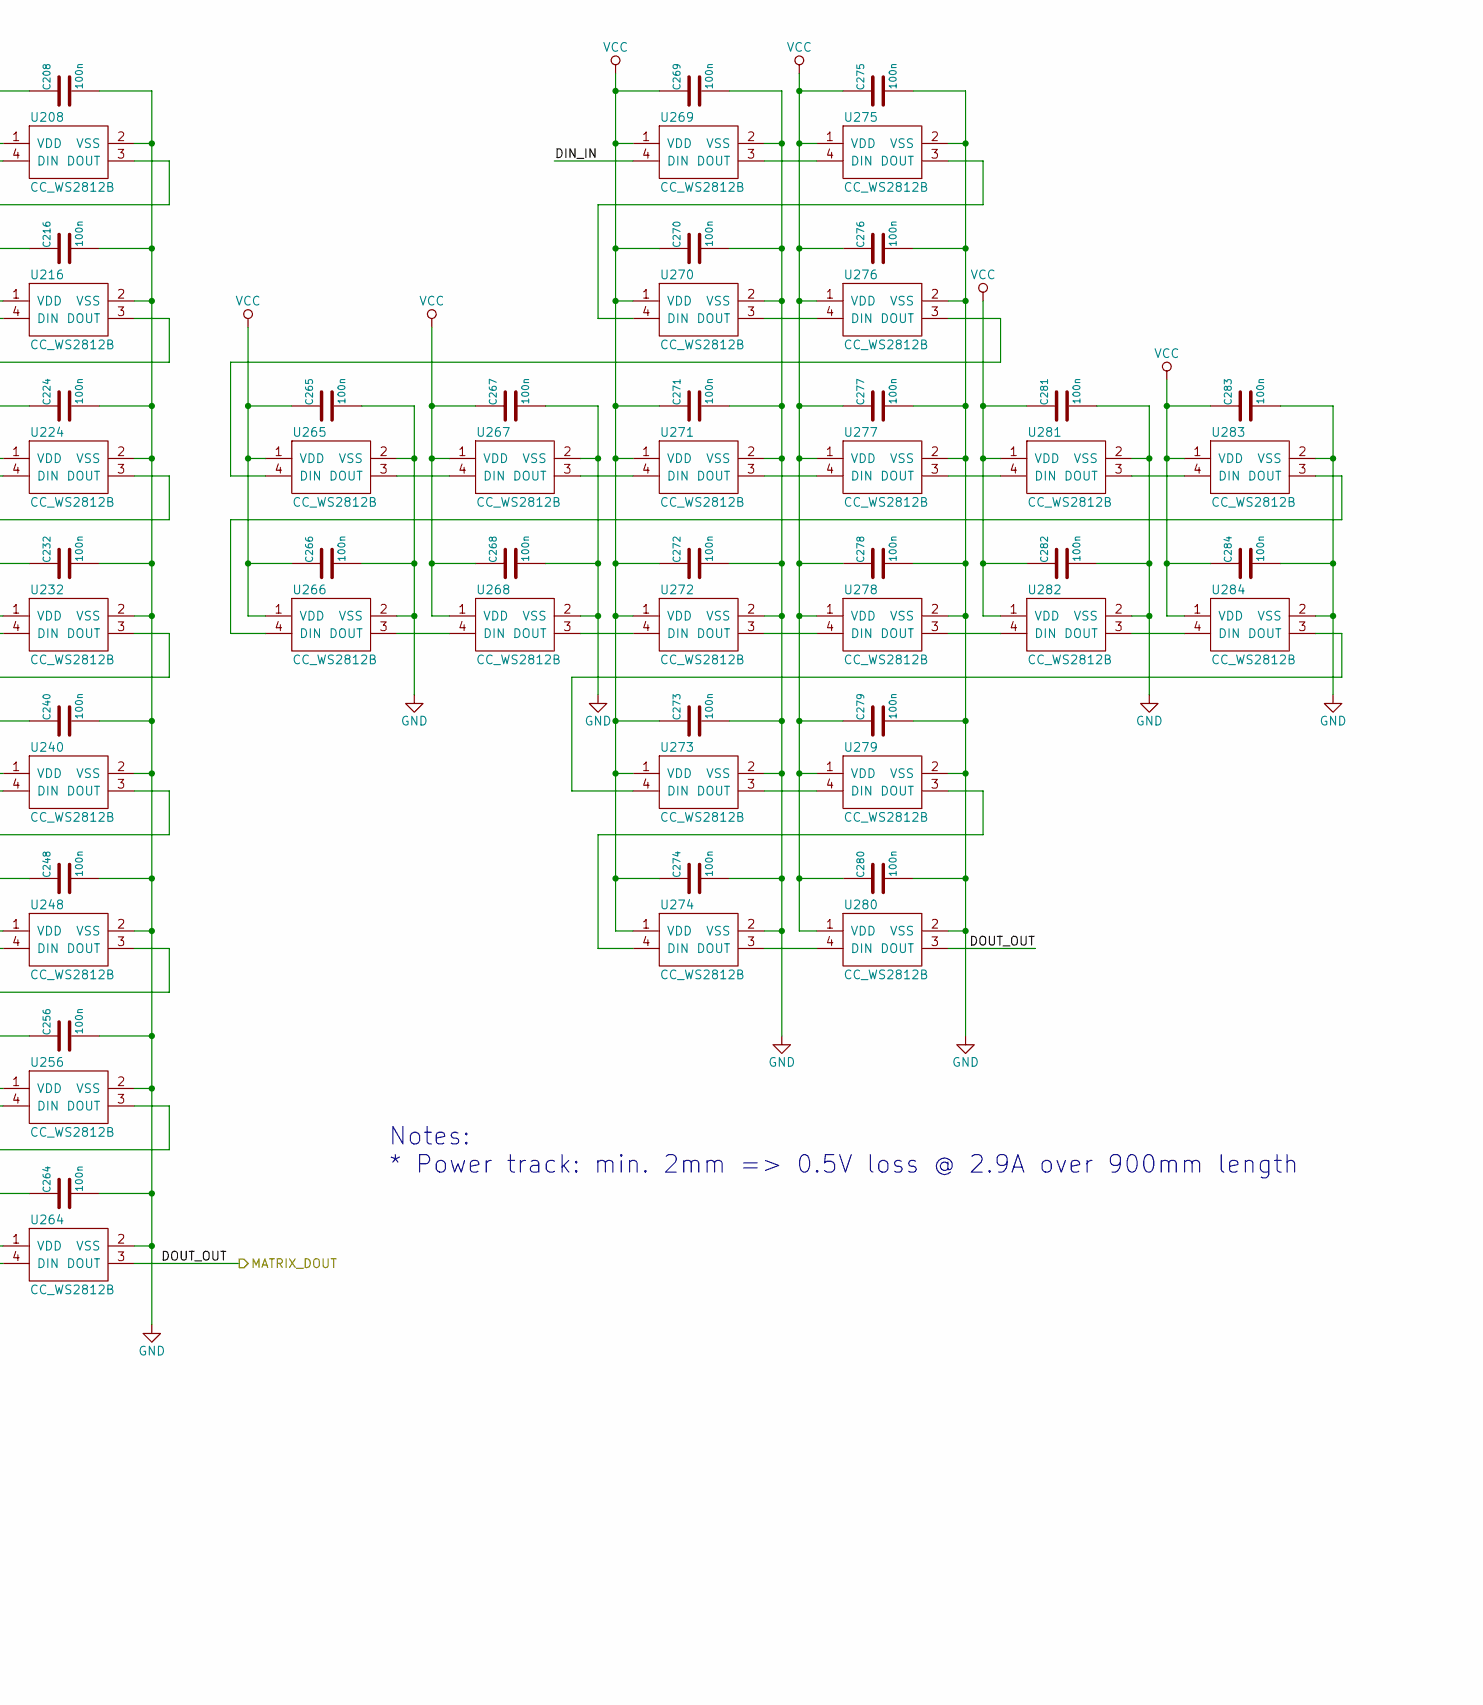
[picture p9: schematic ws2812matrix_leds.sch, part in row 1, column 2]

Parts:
C201, C202, C203, C204, C205, C206, C207, C208, C209, C210, C211, C212, C213, C214, C215, C216, C217, C218, C219, C220, C221, C222, C223, C224, C225, C226, C227, C228, C229, C230, C231, C232, C233, C234, C235, C236, C237, C238, C239, C240, C241, C242, C243, C244, C245, C246, C247, C248, C249, C250, C251, C252, C253, C254, C255, C256, C257, C258, C259, C260, C261, C262, C263, C264, C265, C266, C267, C268, C269, C270, C271, C272, C273, C274, C275, C276, C277, C278, C279, C280, C281, C282, C283, C284: 100n; rcl-cc-0603
M201, M202, M203: CC_MOUNT; CC_MOUNT_PLATED_M3
Q201: MOS_N; CC_SOT23_MOS1
R201, R202: 1k; rcl-cc-0603
U201, U202, U203, U204, U205, U206, U207, U208, U209, U210, U211, U212, U213, U214, U215, U216, U217, U218, U219, U220, U221, U222, U223, U224, U225, U226, U227, U228, U229, U230, U231, U232, U233, U234, U235, U236, U237, U238, U239, U240, U241, U242, U243, U244, U245, U246, U247, U248, U249, U250, U251, U252, U253, U254, U255, U256, U257, U258, U259, U260, U261, U262, U263, U264: CC_WS2812B; WS2812B
U265, U266, U267, U268, U269, U270, U271, U272, U273, U274, U275, U276, U277, U278, U279, U280, U281, U282, U283, U284: CC_WS2812B; WS2812B_8MM

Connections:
/LEDS/DIN_IN: Q201.D, R201.2, U201.4 (DIN), U269.4 (DIN)
GND: C201.2, C202.2, C203.2, C204.2, C205.2, C206.2, C207.2, C208.2, C209.2, C210.2, C211.2, C212.2, C213.2, C214.2, C215.2, C216.2, C217.2, C218.2, C219.2, C220.2, C221.2, C222.2, C223.2, C224.2, C225.2, C226.2, C227.2, C228.2, C229.2, C230.2, C231.2, C232.2, C233.2, C234.2, C235.2, C236.2, C237.2, C238.2, C239.2, C240.2, C241.2, C242.2, C243.2, C244.2, C245.2, C246.2, C247.2, C248.2, C249.2, C250.2, C251.2, C252.2, C253.2, C254.2, C255.2, C256.2, C257.2, C258.2, C259.2, C260.2, C261.2, C262.2, C263.2, C264.2, C265.2, C266.2, C267.2, C268.2, C269.2, C270.2, C271.2, C272.2, C273.2, C274.2, C275.2, C276.2, C277.2, C278.2, C279.2, C280.2, C281.2, C282.2, C283.2, C284.2, M201.1, M202.1, M203.1, Q201.S, R202.1, U201.2 (VSS), U202.2 (VSS), U203.2 (VSS), U204.2 (VSS), U205.2 (VSS), U206.2 (VSS), U207.2 (VSS), U208.2 (VSS), U209.2 (VSS), U210.2 (VSS), U211.2 (VSS), U212.2 (VSS), U213.2 (VSS), U214.2 (VSS), U215.2 (VSS), U216.2 (VSS), U217.2 (VSS), U218.2 (VSS), U219.2 (VSS), U220.2 (VSS), U221.2 (VSS), U222.2 (VSS), U223.2 (VSS), U224.2 (VSS), U225.2 (VSS), U226.2 (VSS), U227.2 (VSS), U228.2 (VSS), U229.2 (VSS), U230.2 (VSS), U231.2 (VSS), U232.2 (VSS), U233.2 (VSS), U234.2 (VSS), U235.2 (VSS), U236.2 (VSS), U237.2 (VSS), U238.2 (VSS), U239.2 (VSS), U240.2 (VSS), U241.2 (VSS), U242.2 (VSS), U243.2 (VSS), U244.2 (VSS), U245.2 (VSS), U246.2 (VSS), U247.2 (VSS), U248.2 (VSS), U249.2 (VSS), U250.2 (VSS), U251.2 (VSS), U252.2 (VSS), U253.2 (VSS), U254.2 (VSS), U255.2 (VSS), U256.2 (VSS), U257.2 (VSS), U258.2 (VSS), U259.2 (VSS), U260.2 (VSS), U261.2 (VSS), U262.2 (VSS), U263.2 (VSS), U264.2 (VSS), U265.2 (VSS), U266.2 (VSS), U267.2 (VSS), U268.2 (VSS), U269.2 (VSS), U270.2 (VSS), U271.2 (VSS), U272.2 (VSS), U273.2 (VSS), U274.2 (VSS), U275.2 (VSS), U276.2 (VSS), U277.2 (VSS), U278.2 (VSS), U279.2 (VSS), U280.2 (VSS), U281.2 (VSS), U282.2 (VSS), U283.2 (VSS), U284.2 (VSS); also elsewhere on the board
unnamed: U201.3 (DOUT), U202.4 (DIN)
unnamed: U202.3 (DOUT), U203.4 (DIN)
unnamed: U203.3 (DOUT), U204.4 (DIN)
unnamed: U204.3 (DOUT), U205.4 (DIN)
unnamed: U205.3 (DOUT), U206.4 (DIN)
unnamed: U206.3 (DOUT), U207.4 (DIN)
unnamed: U207.3 (DOUT), U208.4 (DIN)
unnamed: U208.3 (DOUT), U209.4 (DIN)
unnamed: U209.3 (DOUT), U210.4 (DIN)
unnamed: U210.3 (DOUT), U211.4 (DIN)
unnamed: U211.3 (DOUT), U212.4 (DIN)
unnamed: U212.3 (DOUT), U213.4 (DIN)
unnamed: U213.3 (DOUT), U214.4 (DIN)
unnamed: U214.3 (DOUT), U215.4 (DIN)
unnamed: U215.3 (DOUT), U216.4 (DIN)
unnamed: U216.3 (DOUT), U217.4 (DIN)
unnamed: U217.3 (DOUT), U218.4 (DIN)
unnamed: U218.3 (DOUT), U219.4 (DIN)
unnamed: U219.3 (DOUT), U220.4 (DIN)
unnamed: U220.3 (DOUT), U221.4 (DIN)
unnamed: U221.3 (DOUT), U222.4 (DIN)
unnamed: U222.3 (DOUT), U223.4 (DIN)
unnamed: U223.3 (DOUT), U224.4 (DIN)
unnamed: U224.3 (DOUT), U225.4 (DIN)
unnamed: U225.3 (DOUT), U226.4 (DIN)
unnamed: U226.3 (DOUT), U227.4 (DIN)
unnamed: U227.3 (DOUT), U228.4 (DIN)
unnamed: U228.3 (DOUT), U229.4 (DIN)
unnamed: U229.3 (DOUT), U230.4 (DIN)
unnamed: U230.3 (DOUT), U231.4 (DIN)
unnamed: U231.3 (DOUT), U232.4 (DIN)
unnamed: U232.3 (DOUT), U233.4 (DIN)
unnamed: U233.3 (DOUT), U234.4 (DIN)
unnamed: U234.3 (DOUT), U235.4 (DIN)
unnamed: U235.3 (DOUT), U236.4 (DIN)
unnamed: U236.3 (DOUT), U237.4 (DIN)
unnamed: U237.3 (DOUT), U238.4 (DIN)
unnamed: U238.3 (DOUT), U239.4 (DIN)
unnamed: U239.3 (DOUT), U240.4 (DIN)
unnamed: U240.3 (DOUT), U241.4 (DIN)
unnamed: U241.3 (DOUT), U242.4 (DIN)
unnamed: U242.3 (DOUT), U243.4 (DIN)
unnamed: U243.3 (DOUT), U244.4 (DIN)
unnamed: U244.3 (DOUT), U245.4 (DIN)
unnamed: U245.3 (DOUT), U246.4 (DIN)
unnamed: U246.3 (DOUT), U247.4 (DIN)
unnamed: U247.3 (DOUT), U248.4 (DIN)
unnamed: U248.3 (DOUT), U249.4 (DIN)
unnamed: U249.3 (DOUT), U250.4 (DIN)
unnamed: U250.3 (DOUT), U251.4 (DIN)
unnamed: U251.3 (DOUT), U252.4 (DIN)
unnamed: U252.3 (DOUT), U253.4 (DIN)
unnamed: U253.3 (DOUT), U254.4 (DIN)
unnamed: U254.3 (DOUT), U255.4 (DIN)
unnamed: U255.3 (DOUT), U256.4 (DIN)
unnamed: U256.3 (DOUT), U257.4 (DIN)
unnamed: U257.3 (DOUT), U258.4 (DIN)
unnamed: U258.3 (DOUT), U259.4 (DIN)
unnamed: U259.3 (DOUT), U260.4 (DIN)
unnamed: U260.3 (DOUT), U261.4 (DIN)
unnamed: U261.3 (DOUT), U262.4 (DIN)
unnamed: U262.3 (DOUT), U263.4 (DIN)
unnamed: U263.3 (DOUT), U264.4 (DIN)
unnamed: U265.3 (DOUT), U267.4 (DIN)
unnamed: U265.4 (DIN), U276.3 (DOUT)
unnamed: U266.3 (DOUT), U268.4 (DIN)
unnamed: U266.4 (DIN), U283.3 (DOUT)
unnamed: U267.3 (DOUT), U271.4 (DIN)
unnamed: U268.3 (DOUT), U272.4 (DIN)
unnamed: U269.3 (DOUT), U275.4 (DIN)
unnamed: U270.3 (DOUT), U276.4 (DIN)
unnamed: U270.4 (DIN), U275.3 (DOUT)
unnamed: U271.3 (DOUT), U277.4 (DIN)
unnamed: U272.3 (DOUT), U278.4 (DIN)
unnamed: U273.3 (DOUT), U279.4 (DIN)
unnamed: U273.4 (DIN), U284.3 (DOUT)
unnamed: U274.3 (DOUT), U280.4 (DIN)
unnamed: U274.4 (DIN), U279.3 (DOUT)
unnamed: U277.3 (DOUT), U281.4 (DIN)
unnamed: U278.3 (DOUT), U282.4 (DIN)
unnamed: U281.3 (DOUT), U283.4 (DIN)
unnamed: U282.3 (DOUT), U284.4 (DIN)
VCC: C201.1, C202.1, C203.1, C204.1, C205.1, C206.1, C207.1, C208.1, C209.1, C210.1, C211.1, C212.1, C213.1, C214.1, C215.1, C216.1, C217.1, C218.1, C219.1, C220.1, C221.1, C222.1, C223.1, C224.1, C225.1, C226.1, C227.1, C228.1, C229.1, C230.1, C231.1, C232.1, C233.1, C234.1, C235.1, C236.1, C237.1, C238.1, C239.1, C240.1, C241.1, C242.1, C243.1, C244.1, C245.1, C246.1, C247.1, C248.1, C249.1, C250.1, C251.1, C252.1, C253.1, C254.1, C255.1, C256.1, C257.1, C258.1, C259.1, C260.1, C261.1, C262.1, C263.1, C264.1, C265.1, C266.1, C267.1, C268.1, C269.1, C270.1, C271.1, C272.1, C273.1, C274.1, C275.1, C276.1, C277.1, C278.1, C279.1, C280.1, C281.1, C282.1, C283.1, C284.1, R201.1, U201.1 (VDD), U202.1 (VDD), U203.1 (VDD), U204.1 (VDD), U205.1 (VDD), U206.1 (VDD), U207.1 (VDD), U208.1 (VDD), U209.1 (VDD), U210.1 (VDD), U211.1 (VDD), U212.1 (VDD), U213.1 (VDD), U214.1 (VDD), U215.1 (VDD), U216.1 (VDD), U217.1 (VDD), U218.1 (VDD), U219.1 (VDD), U220.1 (VDD), U221.1 (VDD), U222.1 (VDD), U223.1 (VDD), U224.1 (VDD), U225.1 (VDD), U226.1 (VDD), U227.1 (VDD), U228.1 (VDD), U229.1 (VDD), U230.1 (VDD), U231.1 (VDD), U232.1 (VDD), U233.1 (VDD), U234.1 (VDD), U235.1 (VDD), U236.1 (VDD), U237.1 (VDD), U238.1 (VDD), U239.1 (VDD), U240.1 (VDD), U241.1 (VDD), U242.1 (VDD), U243.1 (VDD), U244.1 (VDD), U245.1 (VDD), U246.1 (VDD), U247.1 (VDD), U248.1 (VDD), U249.1 (VDD), U250.1 (VDD), U251.1 (VDD), U252.1 (VDD), U253.1 (VDD), U254.1 (VDD), U255.1 (VDD), U256.1 (VDD), U257.1 (VDD), U258.1 (VDD), U259.1 (VDD), U260.1 (VDD), U261.1 (VDD), U262.1 (VDD), U263.1 (VDD), U264.1 (VDD), U265.1 (VDD), U266.1 (VDD), U267.1 (VDD), U268.1 (VDD), U269.1 (VDD), U270.1 (VDD), U271.1 (VDD), U272.1 (VDD), U273.1 (VDD), U274.1 (VDD), U275.1 (VDD), U276.1 (VDD), U277.1 (VDD), U278.1 (VDD), U279.1 (VDD), U280.1 (VDD), U281.1 (VDD), U282.1 (VDD), U283.1 (VDD), U284.1 (VDD); also elsewhere on the board
WS2811_DIN: Q201.G, R202.2; also elsewhere on the board
WS2811_DOUT: U264.3 (DOUT), U280.3 (DOUT); also elsewhere on the board

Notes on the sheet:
Notes: * Power track: min. 2mm => 0.5V loss @ 2.9A over 900mm length

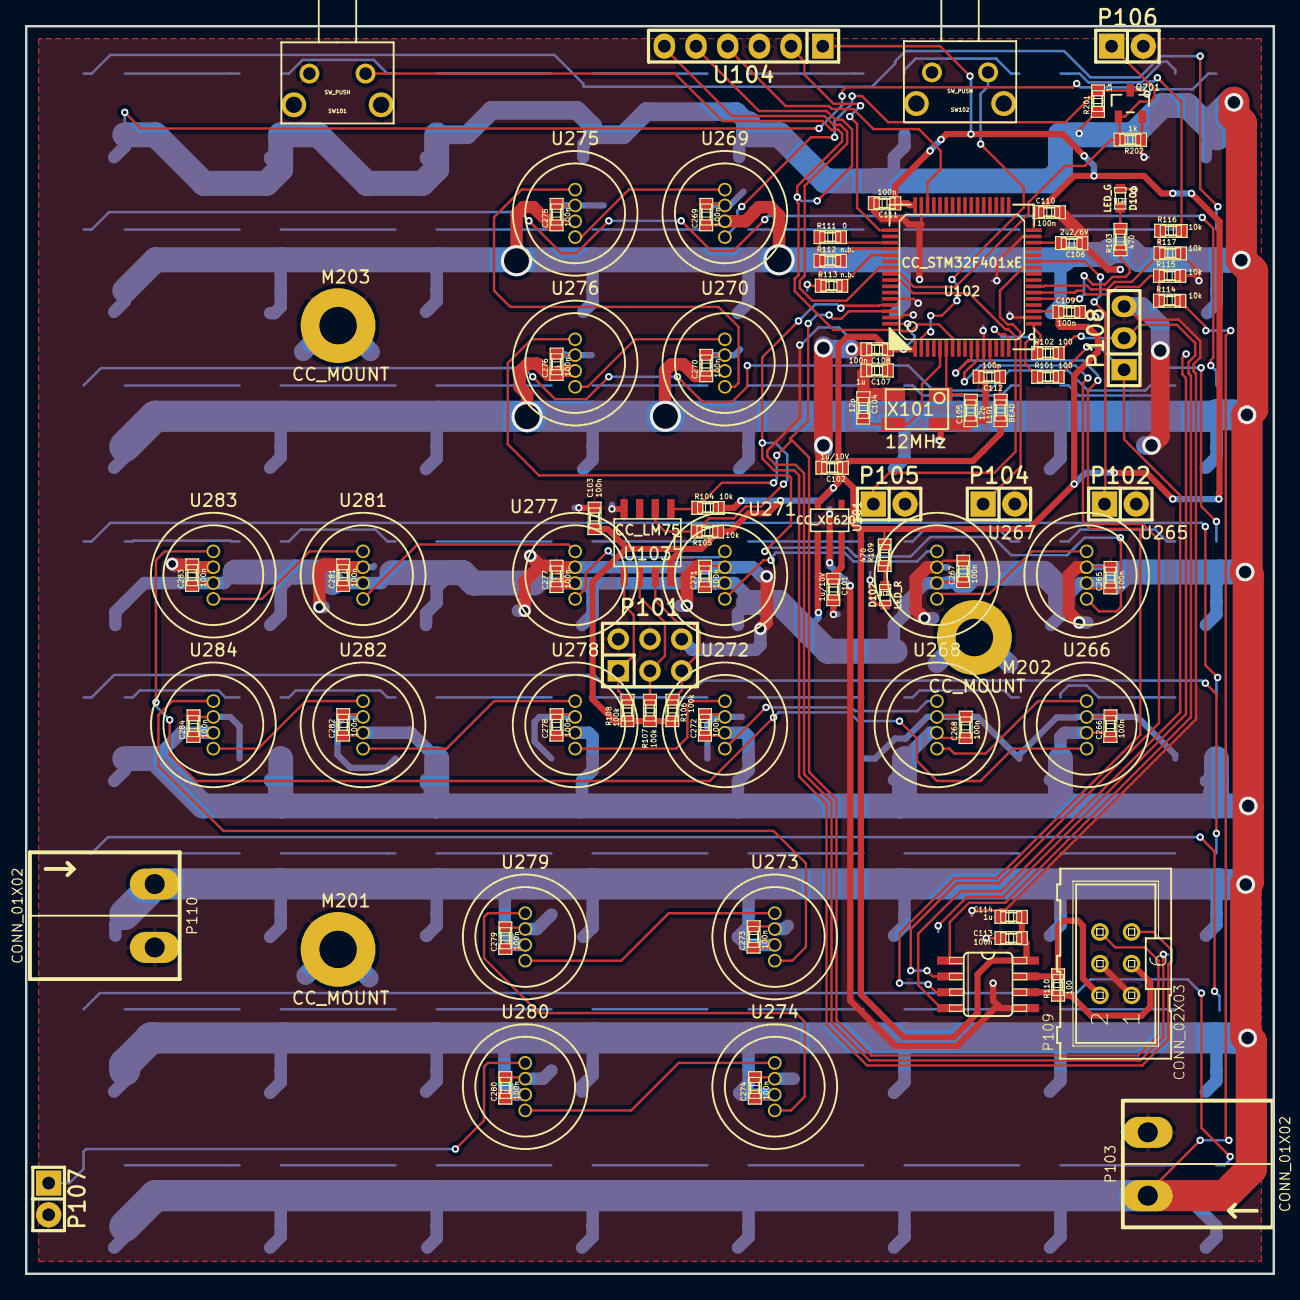
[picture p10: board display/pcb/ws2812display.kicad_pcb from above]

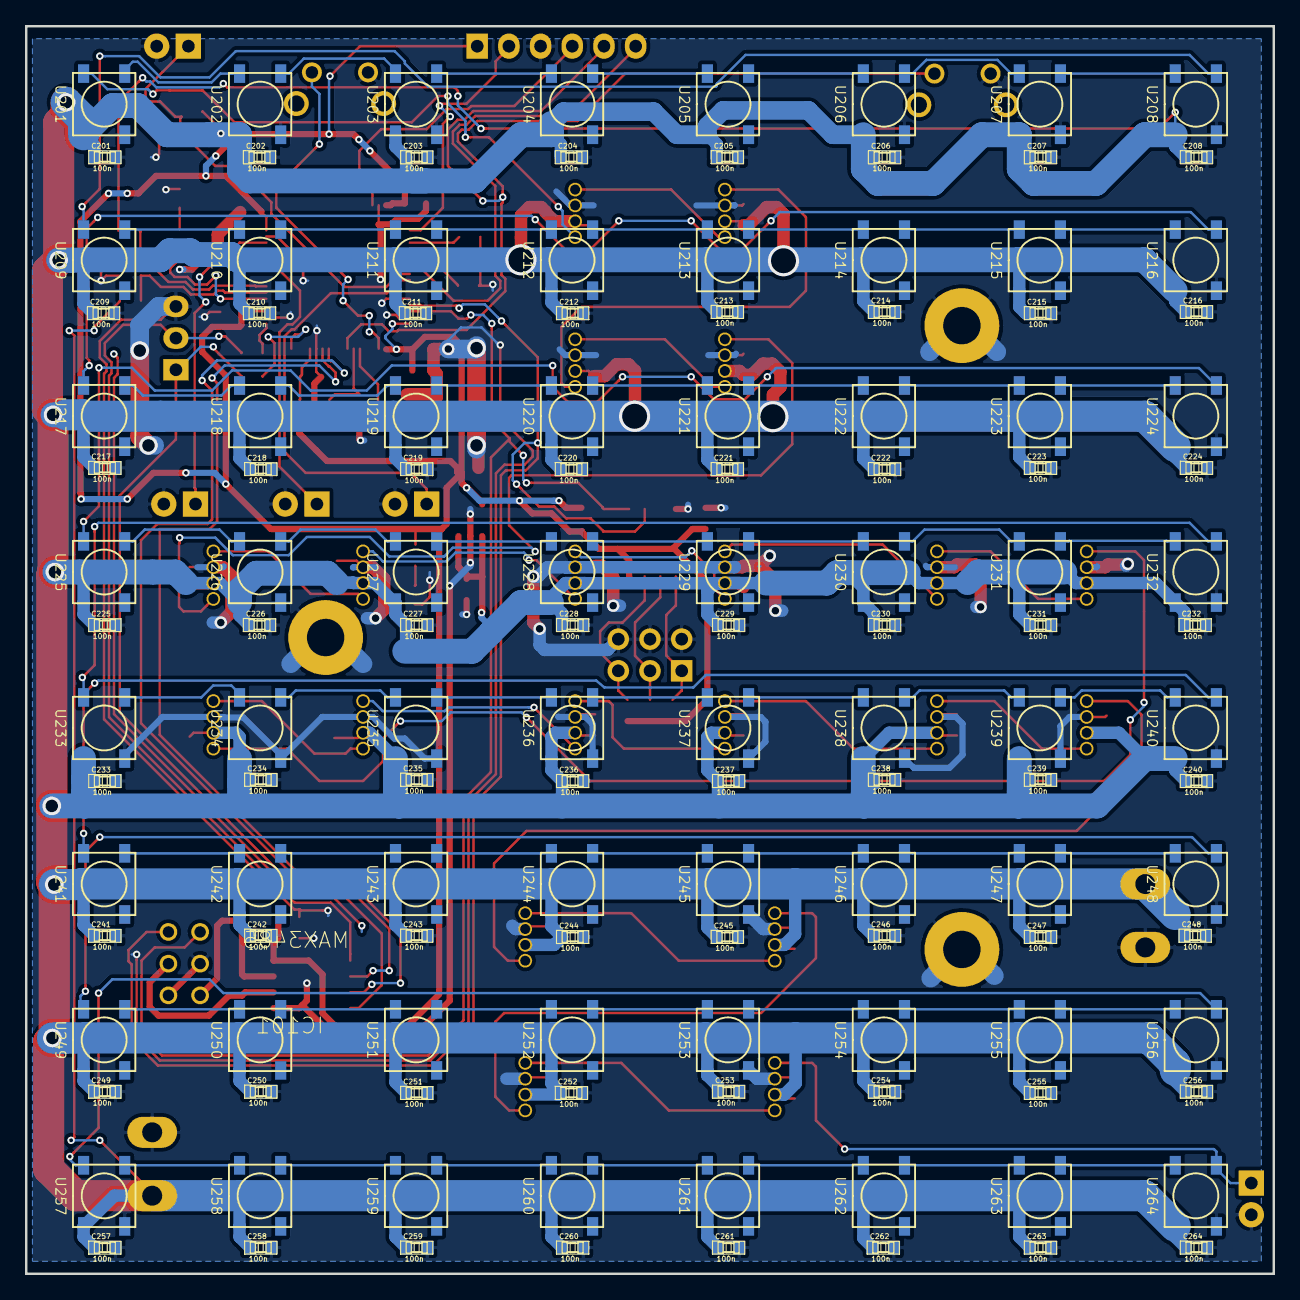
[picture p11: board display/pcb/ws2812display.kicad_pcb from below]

Board: 2 copper layers, 100.0 x 100.0 mm, 226 parts (128 on the bottom side), 121 nets.

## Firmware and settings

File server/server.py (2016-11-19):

#!/usr/bin/python3
#
#	Plussy Display
#	Copyright (C) 2015  Christian Carlowitz <chca@cmesh.de>
#
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

import sys
import socket
import socketserver
import selectors
import threading
import time
import queue
import xmlrpc.client
import serial

########################################################################
# Utility
########################################################################

class SelectableQueue(queue.Queue):
	def __init__(self):
		super().__init__()
		self.__txsock, self.__rxsock = socket.socketpair()
	
	def fileno(self):
		return self.__rxsock.fileno()
	
	def put(self, item):
		super().put(item)
		self.__txsock.send(b".")
	
	def get(self):
		self.__rxsock.recv(1)
		return super().get()

class ConnectionManager:
	def __init__(self):
		self.conns = {}
	
	def add(self, port, q):
		self.conns[port] = q
		
	def remove(self, port):
		del self.conns[port]
		
	def sendBroadcast(self, msg):
		for q in self.conns.values():
			q.put(msg)

mgr = ConnectionManager()

########################################################################
# Discovery Broadcast
########################################################################

# send an UDP broadcast packet every second on first available interface (usually eth0)
class BroadcastThread(threading.Thread):
	def __init__(self, interface):
		super().__init__()
		self.contRun = True # stores wheather to exit thread
		self.s = socket.socket(socket.AF_INET, socket.SOCK_DGRAM)  # UDP socket
		self.s.setsockopt(socket.SOL_SOCKET, socket.SO_REUSEADDR, 1)  # allow multiple program starts ;-)
		self.s.setsockopt(socket.SOL_SOCKET, socket.SO_BROADCAST, 1) # broadcast
		self.s.bind((interface,0)) # use interface that has given address associated
		self.ip = interface
	
	def run(self):
		while self.contRun:
			time.sleep(1) # send every second
			self.s.sendto(("plussyDisplay@"+self.ip).encode(), ("255.255.255.255", 60000)) # send magic packet
		
	def stop(self):
		self.contRun = False

########################################################################
# Hardware Thread
########################################################################

class HardwareRequest():
	def __init__(self, command, replyQueue):
		self.command = command # string command
		self.replyQueue = replyQueue # queue object for reply

requestQueue = queue.Queue() # thread-safe queue

class HardwareThread(threading.Thread):
	def __init__(self, serialPort):
		super().__init__()
		self.contRun = True
		
		self.s = None
		if serialPort != None:
			self.s = serial.Serial(serialPort, 115200, timeout=2)
	
	def run(self):
		if self.s == None:
			sim = xmlrpc.client.ServerProxy("http://localhost:8000") # Debug only!
		lastM = None
		while self.contRun:
			try:
				req = requestQueue.get(timeout=1)
			
				if (req.command[0] == "r") and (lastM != None): # quick reply for read command if we know the state
					req.replyQueue.put("R"+lastM[1:])
				else: # hardware query
					#print("hw: " + req.command)
					
					if self.s == None:
						# Debug: Send to simulation program
						ans = sim.cmd(req.command)
					else:
						# real hardware: use serial protocol
						self.s.write( ("!%02x%s;" % (len(req.command), req.command)).encode() )
						self.s.flush()
						tmp = ""
						while tmp != "@":
							tmp = self.s.read(1).decode()
							if tmp == "":
								raise Exception("timeout")
						l = int(self.s.read(2).decode(),16)
						ans = self.s.read(l).decode()
						e = self.s.read(1).decode()
						if e != ";":
							raise Exception("invalid end of response")
					
					if ans[0] == "M": # store answer for quick replies if command was 'm'
						lastM = ans
						mgr.sendBroadcast(ans) # send changes to all clients
					else:
						req.replyQueue.put(ans)
				
			except queue.Empty:
				pass
			except serial.SerialException as e:
				print(e)
			except Exception as e:
				print(e)
		
	def stop(self):
		self.contRun = False

########################################################################
# Threaded TCP Server
########################################################################

class PlussyTCPHandler(socketserver.StreamRequestHandler):
	def handle(self):
		self.q = SelectableQueue() # thread-safe queue for replies
		tname = threading.current_thread().name # thread name
		ip,port = self.request.getpeername() # peer ip and port (as tuple)
		label = tname + ", ip=" + ip + ", port=" + str(port) + ": "
		mgr.add(port,self.q)
		print(label + "new connection")
		
		sel = selectors.DefaultSelector()
		sel.register(self.rfile, selectors.EVENT_READ, \
			lambda: self.user_cmd())
		sel.register(self.q, selectors.EVENT_READ, \
			lambda: self.user_ans())
		
		while True:
			events = sel.select()
			err = False
			for key,mask in events:
				if not key.data():
					err = True
			if err:
				break

		mgr.remove(port)
		print(label + "disconnect")
		
	def user_cmd(self):
		req = self.rfile.readline().decode().strip() # get one line from socket
		if len(req) == 0: # socket has probably been closed
			return False
		#print(label + "got request", "\"" + req + "\"")
		
		requestQueue.put(HardwareRequest(req, self.q)) # send request to hardware thread
		return True
		
	def user_ans(self):
		resp = self.q.get() # get reply from reply queue
		self.wfile.write((resp+"\n").encode()) # send reply to peer
		return True

class ThreadedTCPServer(socketserver.ThreadingMixIn, socketserver.TCPServer):
	allow_reuse_address = True


########################################################################
# Main
########################################################################

if __name__ == "__main__":

	if len(sys.argv) < 2:
		print("usage: server.py INTERFACE [SERIAL]")
		print("example (simulation): server.py 192.168.0.1")
		print("example (hardware): server.py 192.168.0.1 /dev/ttyO1")
		sys.exit(1)

	# get interface ip
	interface = sys.argv[1]
	
	# get serial
	serialPort = None
	if len(sys.argv) > 2:
		serialPort = sys.argv[2]
	
	# start broadcast thread
	bt = BroadcastThread(interface)
	bt.start()
	
	# start hardware thread
	hwt = HardwareThread(serialPort)
	hwt.start()
	
	# start tcp server
	srv = ThreadedTCPServer((interface, 60000), PlussyTCPHandler)
	srvThread = threading.Thread(target=srv.serve_forever)
	srvThread.daemon = True
	srvThread.start()
	
	try:
		while True:
			time.sleep(1)
	except KeyboardInterrupt:
		print("exit request, exiting ...")
		# stop broadcast thread
		bt.stop()
		hwt.stop()
		bt.join()
		hwt.join()
		# stop server thread
		srv.shutdown()
		srv.server_close()

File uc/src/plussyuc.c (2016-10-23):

/*
	Plussy Display
	Copyright (C) 2016  Christian Carlowitz <chca@cmesh.de>

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
	You should have received a copy of the GNU General Public License
	along with this program.  If not, see <http://www.gnu.org/licenses/>.
*/

#define PLUSSYUC_C_

#include <libopencm3/stm32/rcc.h>
#include <libopencm3/stm32/flash.h>
#include <libopencm3/stm32/gpio.h>
#include <stdio.h>
#include <string.h>

#include "boot.h"
#include "hwinit.h"
#include "ws2811.h"
#include "util.h"
#include "usart.h"
#include "usb.h"
#include "cmd.h"
#include "animations/common.h"

static void gpio_setup(void)
{
	rcc_periph_clock_enable(RCC_GPIOA);
	gpio_mode_setup(GPIOA, GPIO_MODE_OUTPUT, GPIO_PUPD_NONE, GPIO5);
}

static void btn_setup(void)
{
	rcc_periph_clock_enable(RCC_GPIOC);
	gpio_mode_setup(GPIOC, GPIO_MODE_INPUT, GPIO_PUPD_PULLUP, GPIO13);
}

static uint8_t btn_pressed(void)
{
	return (GPIOC_IDR & (1<<13)) ? 0 : 1;
}

const struct rcc_clock_scale clock_config =
{ // 48MHz
	.pllm = 12,
	.plln = 96,
	.pllp = 2,
	.pllq = 2,
	.pllr = 0,
	.hpre = RCC_CFGR_HPRE_DIV_NONE,
	.ppre1 = RCC_CFGR_PPRE_DIV_2,
	.ppre2 = RCC_CFGR_PPRE_DIV_2,
	.power_save = 1,
	.flash_config = FLASH_ACR_ICE | FLASH_ACR_DCE |
			FLASH_ACR_LATENCY_3WS,
	.ahb_frequency  = 48000000,
	.apb1_frequency = 24000000,
	.apb2_frequency = 24000000,
};


int main(void)
{
#ifdef BOOT
	boot_check();
	boot_setup();
#else
	// non-bootloader: move vector table to user space
	scb_move_vector_table(0x10000);
#endif

	rcc_clock_setup_hse_3v3(&clock_config);
	gpio_setup();
	hwversion_setup();
	btn_setup();
	tmr_setup();
	usart_setup();
	cmd_setup();
	
	struct plussy_params p;

	// allocate data
	p.rgbDataLen = WS2811_NLEDS*3;
	uint8_t rgbData[p.rgbDataLen];
	uint8_t rgbDataManual[p.rgbDataLen];
	uint8_t rgbDataDev[p.rgbDataLen]; // data mapped to device version
	p.rgbData = rgbData;
	p.rgbDataManual = rgbDataManual;
	p.rgbDataDev = rgbDataDev;

	// initialize (LED-)hardware
	hwinit(&p);
	
	// init usb
	if(p.hwver >= 2)
		usb_setup();

	// init led driver
	ws2811_setup(p.ws2811_options);

	// main loop
	p.compTime = 0;
	uint8_t btnLastPressed = 0;


#ifdef BOOT
	ws2811_update(rgbDataDev);
#endif

	while (1)
	{
#ifdef BOOT
		if(tmr_done())
		{
			// toggle LED
			gpio_toggle(GPIOA, GPIO5);
			// configure toggle led timer
			tmr_delay_ms(200);
		}
#else
		// toggle LED
		gpio_toggle(GPIOA, GPIO5);
		// configure display update timer with period per frame (100 Hz)
		tmr_delay_us(10000);
#endif
		
		// check for commands
		if(p.hwver >= 2)
			usb_poll();
		cmd_proc(&p);

		// check if button pressed (de-bouncing through 10ms loop delay)
		if(!btnLastPressed && btn_pressed())
		{
			#ifndef BOOT
			if(p.animSel == p.animSelMax)
				p.animSel = -1;
			else
				p.animSel++;
			#endif
			btnLastPressed = 1;
		}
		else if(!btn_pressed())
		{
			btnLastPressed = 0;
		}

#ifndef BOOT
		// calculate next frame
		if(p.animSel >= 0)
			animTable[p.animSel].func(p.rgbData, p.rgbDataLen);
		// remap data
		if(p.animSel < 0)
			p.hwmap(p.rgbDataManual, rgbDataDev);
		else
			p.hwmap(p.rgbData, rgbDataDev);
		// scale brightness
		for(uint8_t i = 0; i < WS2811_NLEDS; i++)
			bscale(rgbDataDev+3*i, p.brightnessScale);
		// determine how much time has passed
		p.compTime = tmr_get_status(); // TODO: ouput to serial port?
		// wait if frame time has not yet passed
		while(!tmr_done())
			usb_poll();
		// trigger display update
		ws2811_update(rgbDataDev);
#endif
	}

	return 0;
}

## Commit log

2015-09-04 added (mostly) empty skeleton for uc code - lets an led blink
    [nucleo_f401re_ftdiswd.cfg]
2015-09-06 implemented simple ws2811 led matrix control and basic demo
2015-09-09 refactored code to separate animations from ws2811 driver
2015-09-09 added missing design files for mechanical frame, updated top plate
2015-09-11 fixed bug in led driver
    [ws2811.c]
2015-09-12 added missing license statements
    [testclient.py]
2015-09-16 manage buffer in main program, implemented separate buffer for manual led changes
2015-09-17 allow changing animation with user button
2015-09-18 fixed issue with sscanf writing on wrong memory locations
    [plussyuc.c]
2015-09-18 minor improvements on server, added init script, fixed hostapd for open wlan
    [server.py, server_web.py]
2015-12-12 added pcb files
    [ws2812display.kicad_pcb, ws2812display.sch, ws2812matrix_leds.sch]
2016-01-08 implemented hardware version detection and led position remapping for new plussy pcb
2016-02-05 fixed missing button pullup with new hw revision, added some comments
    [plussyuc.c]
2016-02-11 added server install instructions for apache cgi mod and uart5
2016-02-11 fixed addressing order for hwversion rev1
    [hwversion.c]
2016-05-22 added license statements for config files
    [nucleo_f401re_ftdiswd.cfg]
2016-05-22 added KiCad backup files to ignore list
2016-05-22 fixed license statements for svg and kicad files
    [ws2812display.kicad_pcb, ws2812display.sch, ws2812matrix_leds.sch]
2016-07-09 added v2 display design
    [ws2812display.kicad_pcb, ws2812display.sch, ws2812matrix_leds.sch]
2016-08-26 fixed clock setup for current libopencm3 version
    [plussyuc.c]
2016-08-26 assure reasonable default behavior for unknown hardware revision (fixed crash on null function pointer dereferencing)
    [hwversion.c, plussyuc.c]
2016-08-27 added LED mapping for hardware rev2
2016-08-27 fixed clock setup (APB1 only has 42 MHz max.)
    [util.c, ws2811.c]
2016-08-27 final pcb design for v2
    [ws2812display.kicad_pcb, ws2812matrix_leds.sch]
2016-08-27 added hardware version setting for WS2812B SMD assembly
    WS2812B LEDs have swapped color bits compared to WS2811 controllers
    [hwversion.c, plussyuc.c]
2016-09-05 added usb cdcacm loopback device, changed clock to work
2016-09-06 fixed indexing bug in usb state machine
    [usb.c]
2016-09-06 fixed usb write for blocks larger than 64 bytes
    [usb.c]
2016-10-16 added hwver 7 (lightctrl) with non-inverted data line
    [plussyuc.c, ws2811.c]
2017-03-04 added bottom plate for beagle bone black
2017-03-13 added new laser templates for smd version and beagleboneblack backside
2017-03-13 fixed position errors in top plate v2
2017-03-13 fixed screw positions for bottom plate (separate v2 version)
2017-04-09 added option to switch between ws2811 clock speed modes
2017-04-10 fixed baud rate for new code with changed clock for usb
    [usart.c]

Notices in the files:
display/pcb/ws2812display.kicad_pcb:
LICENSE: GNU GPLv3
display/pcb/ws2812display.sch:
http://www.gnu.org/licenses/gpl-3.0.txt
